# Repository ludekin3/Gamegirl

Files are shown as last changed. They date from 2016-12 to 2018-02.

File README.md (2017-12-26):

# Gamegirl

The most portable way to play LÖVE, PICO-8, Scratch or your favorite emulated games. Powered by RetroArch!

<p align="center">
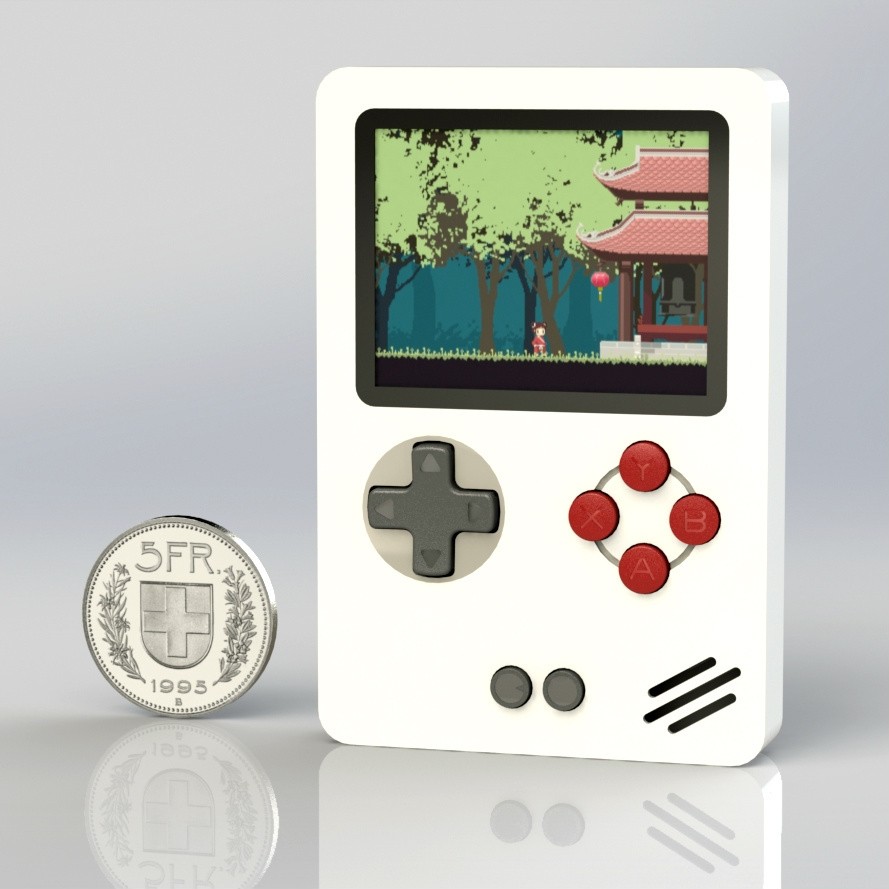
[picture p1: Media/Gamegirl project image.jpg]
Gamegirl
    
</p>

# Table of Contents

* [Description](#description)
* [Components](#components)
* [Build your own!](#build-your-own)
* [Setup](#setup)
* [Team](#team)
* [License](#license)

# Description
We develop a very small, affordable and portable gaming console with a 320x240 display at 120 FPS run by a Raspberry Pi Zero.
Gamegirl runs on the Lakka distribution powered by RetroArch because of its speed, fast power-on, instant power-off and its potential to run many retro and hipster-retro games (LÖVE, PICO-8, Scratch and emulators).

[**Join us on our Discord Chat Channel!**](https://discord.gg/TZ7MZEu)

<p align="center">
    <a href="http://www.youtube.com/watch?feature=player_embedded&v=z5BJ5ywMKEQ" target="_blank">Gamegirl Prototype v0.2</a>
</p>

**Project Goals:**
* Hardware accelerated display
* Custom software (Lakka / RetroArch)
* High quality case and buttons
* Small form factor

# Components
* 1 x Gamegirl custom PCB (audio, power, etc.)
* 1 × Raspberry Pi Zero
* 1 × 2.4" TFT display 320x240 (RGB 565 @ 120 FPS)
* 10 × soft rubber dome buttons
* 2 x metal dome buttons
* 1 × 15-16mm speaker
* 1 × 800+ mAh battery

# Build your own!

## Prototype v0.2 (_released_)
**v0.2** is the current development platform with multiple working prototypes in the field. It works but it's not perfect, yet!

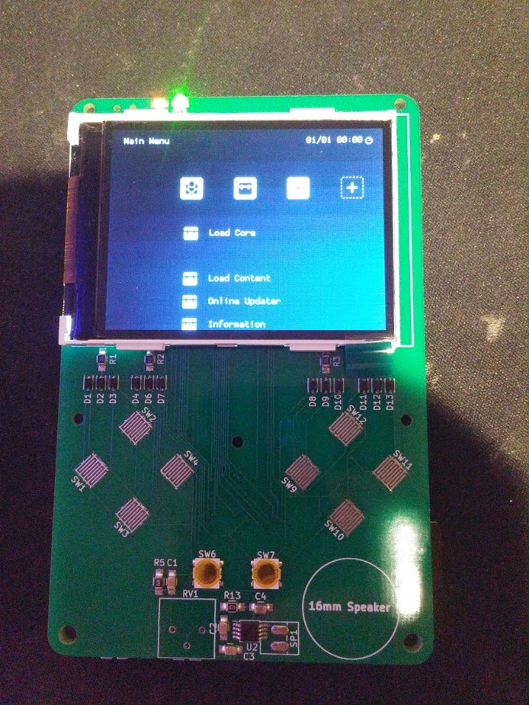
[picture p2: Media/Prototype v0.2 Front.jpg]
Prototype v0.2 Front

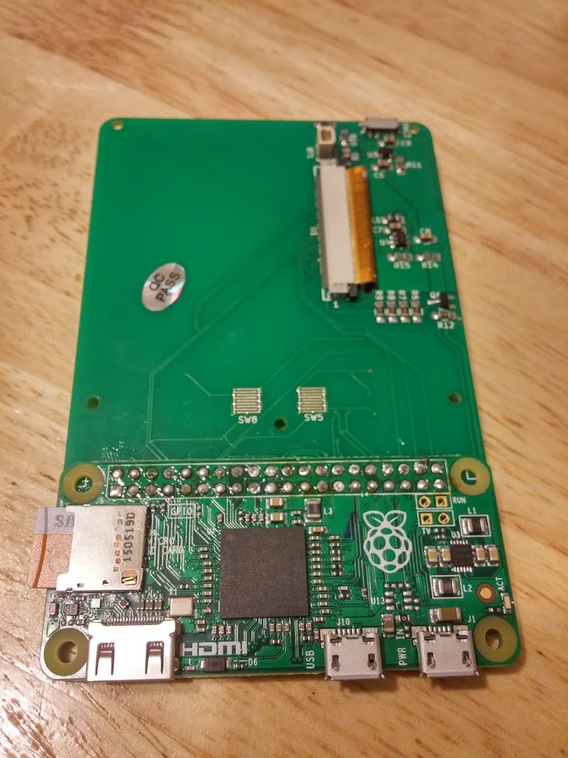
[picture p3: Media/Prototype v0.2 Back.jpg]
Prototype v0.2 Back


### Gamegirl v0.2 - Schematic
* [Gamegirl_v0.2_Schematic.pdf](./Electronics%20v0.2/Gamegirl_v0.2_Schematic.pdf)

### Gamegirl v0.2 - Bill Of Materials (BOM)
* [Octopart - Gamegirl v0.2 BOM](https://octopart.com/bom-tool/0X5BikOH)

#### Minimal assembly variant
In this assembly variant you will get a working prototype without battery/charging and audio functionality. You can use it only while the Raspberry Pi Zero is connected to a USB power supply!
* [Gamegirl v0.2 BOM - minimal assembly variant](./Electronics%20v0.2/Gamegirl_v0.2_BOM_minimal.pdf)

#### Full assembly variant
This assembly variant requires some circuit modifications to get audio output!
* [Gamegirl v0.2 BOM - full assembly variant](./Electronics%20v0.2/Gamegirl_v0.2_BOM.pdf)

### Gamegirl Case v0.2
A 3D printable case design is currently in work.

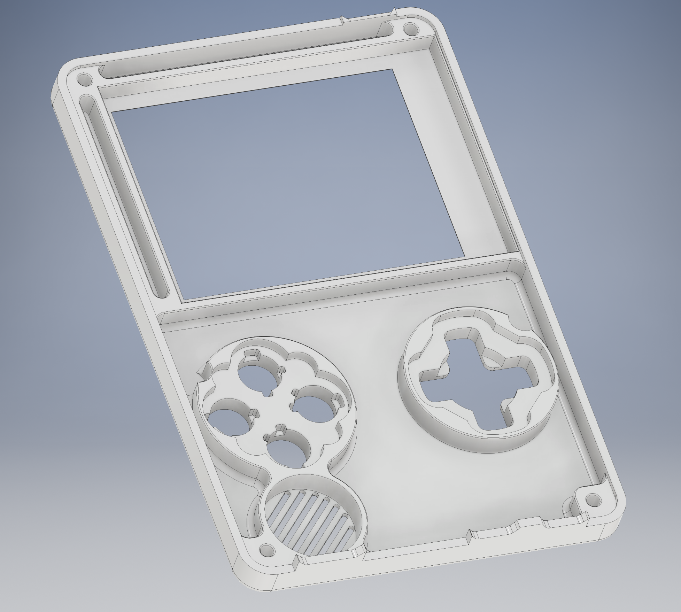
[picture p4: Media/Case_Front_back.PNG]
Case front design model


## Prototype v0.2.1 (Awaiting Prototype board)
**v0.2.1** incorporates multiple improvements and fixes over v0.2. If you do not have a v0.2, you should wait for this!

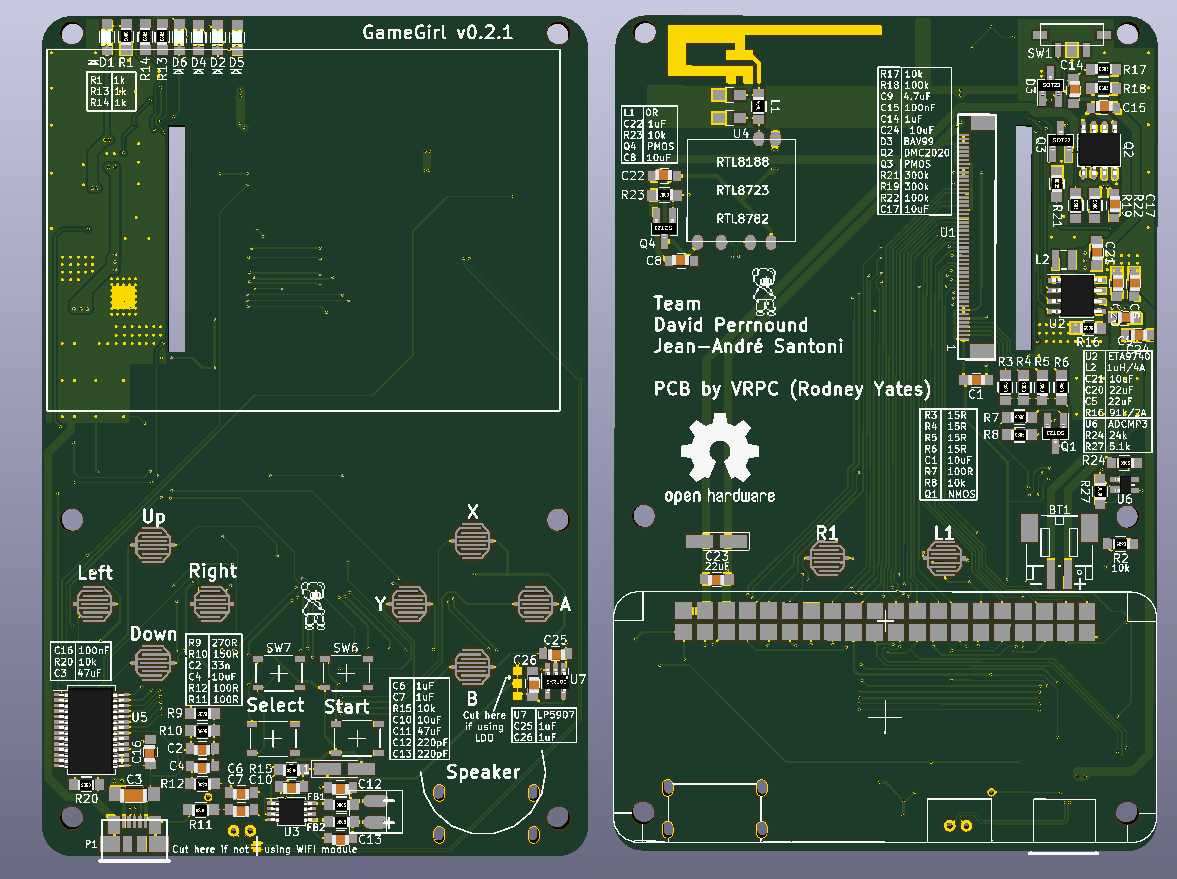
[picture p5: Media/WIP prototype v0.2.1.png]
Prototype v0.2.1 Front


**Improvements over v0.2:**
* Friendlier hand solderable layout (All component footprints have been expanded for soldering without a heatgun)
* Fixed mono audio circuit (better pre and post filtering)
* Fixed backlight function
* Button placement and labeling to reflect standard Nintendo layout
* MCP23S17 GPIO Expander replaced Charlieplexed buttons
* Labeled most 
* Ability to add common inexpensive WiFi adpater directly to the board (depreciated due to Zero W)
* Replaced battery charger and 5v booster ICs with a 3-in-1 IC, ETA9740
** Rpi Zero will run directly from battery (Rpi stability has been tested down to 3.0V)
** Increased charging current from 500mA to 2A or 3A
** 5V Boost will operate in USB-OTG mode for accessories
* Added dedicated charging micro USB port (Rpi ports will be covered)
* Added multiple power decoupling capacitors for better power filtering
* Added Safe Soft-Shutdown circuit
* Replaced latching switch with momentary switch
* (Optional) Low Battery shutdown
* (Optional) Low Noise LDO for audio amp (Must cut 3.3v trace when using)

### Gamegirl v0.2.1 - Bill Of Materials (BOM)
[BOM](./Electronics%20v0.2.1/Gamegirl_v0.2.1_BOM.csv)

### Gamegirl Case v0.2.1
(work in progress)

# Setup
## Install the latest Lakka image on an SD Card

**Gamegirl Raspberry Pi Zero images:**
* [Nightly Builds](http://sources.lakka.tv/nightly/Gamegirl.arm-8.0/)
* [Build r21684 (November 29, 2016)](http://static.kivutar.me/Lakka-Gamegirl.arm-devel-20161129161645-r21684-g895e996.img.gz)
* [Build r21570 (August 23, 2016)](http://static.kivutar.me/Lakka-Gamegirl.arm-devel-20160823060147-r21570-g1cacbe2.img.gz)

**Instructions:**
* [How to write a image to an SD card on Windows & Mac OS](http://trendblog.net/install-raspbian-sd-card-os-x-windows/)

## First boot
As of nightly build 20170110005640-r25097, the system will take longer to boot as it is expanding the SD card partition and running other first boot operations. Subsequent boots will be faster.

## Installing your games
How-to [on lakka.tv](http://www.lakka.tv/get/linux/rpi/install/first-boot/games/)

# Team
| David Perrenoud | Jean-André Santoni |  Rodney Yates
| --- | --- | --- |
| [David Perrenoud](https://github.com/davidperrenoud) | [Jean-André Santoni](http://www.kivutar.me/) - [Github](https://github.com/Kivutar) | [Rodney Yates](https://github.com/zybeon)

- [Jean-André] from France is the software guy of this project. He is the main Lakka developer and a top 5 RetroArch contributor.
- [David] from Switzerland is the hardware guy.
- [Rodney] from US is the PCB designer.

## Contributing
[Join us on our Discord Chat Channel!](https://discord.gg/TZ7MZEu)

### Project Task Tracker
[Trello page](https://trello.com/b/wslfYlVv/gamegirl)

#License

All hardware is covered under [OSHW](https://www.oshwa.org/definition/).

All software is covered under [GNU-GPL 3.0](https://opensource.org/licenses/GPL-3.0).

Permission is hereby granted, free of charge, to any person obtaining a copy of this software and associated documentation files (the "Software"), to deal in the Software without restriction, including without limitation the rights to use, copy, modify, merge, publish, distribute, sublicense, and/or sell copies of the Software, and to permit persons to whom the Software is furnished to do so, subject to the following conditions:  The above copyright notice and this permission notice shall be included in all copies or substantial portions of the Software. THE SOFTWARE IS PROVIDED "AS IS", WITHOUT WARRANTY OF ANY KIND, EXPRESS OR IMPLIED, INCLUDING BUT NOT LIMITED TO THE WARRANTIES OF MERCHANTABILITY, FITNESS FOR A PARTICULAR PURPOSE AND NONINFRINGEMENT. IN NO EVENT SHALL THE AUTHORS OR COPYRIGHT HOLDERS BE LIABLE FOR ANY CLAIM, DAMAGES OR OTHER LIABILITY, WHETHER IN AN ACTION OF CONTRACT, TORT OR OTHERWISE, ARISING FROM, OUT OF OR IN CONNECTION WITH THE SOFTWARE OR THE USE OR OTHER DEALINGS IN THE SOFTWARE."

GNU GPLv3 Logo

OSHW Logo

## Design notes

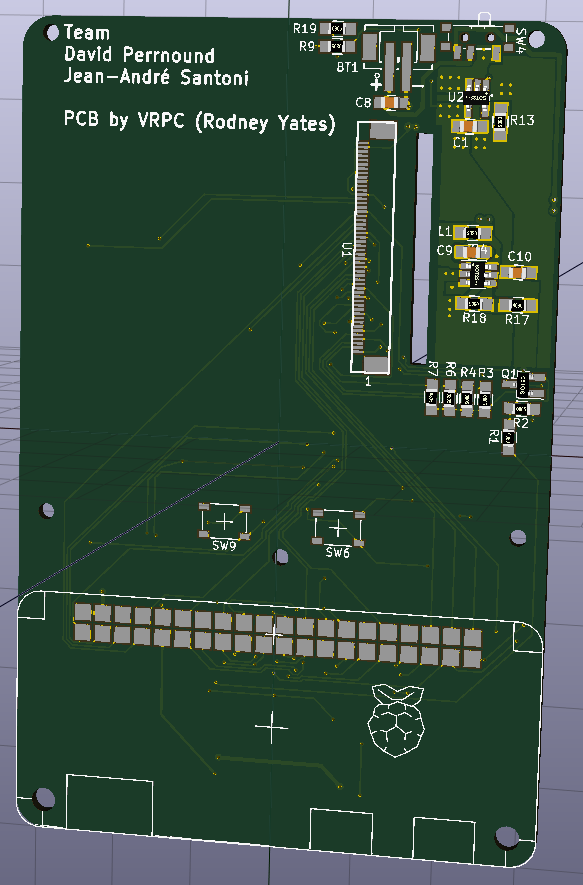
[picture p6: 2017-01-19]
Media/Design_Proto_v0.2.1_back.png

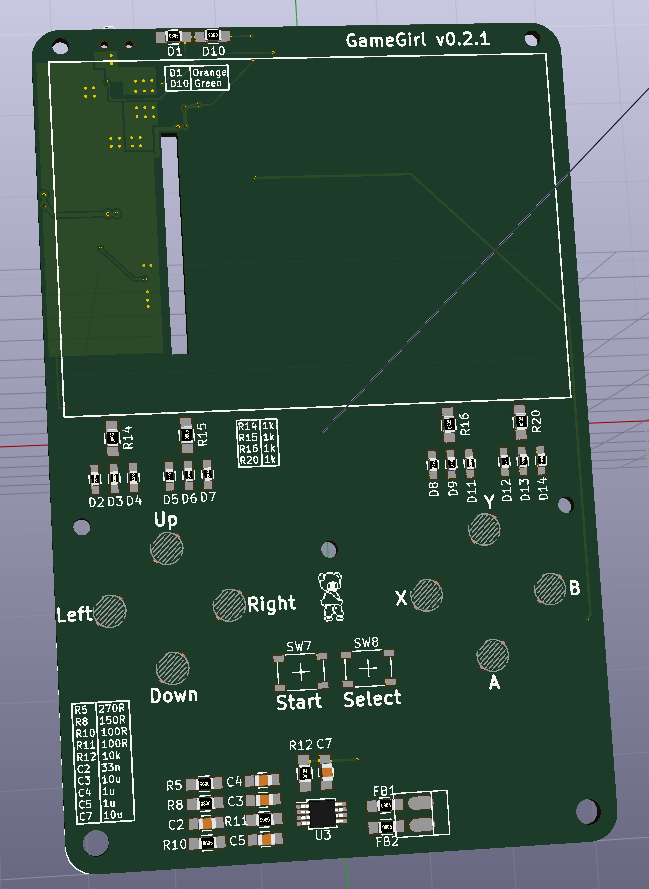
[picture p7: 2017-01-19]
Media/Design_Proto_v0.2.1_front.png

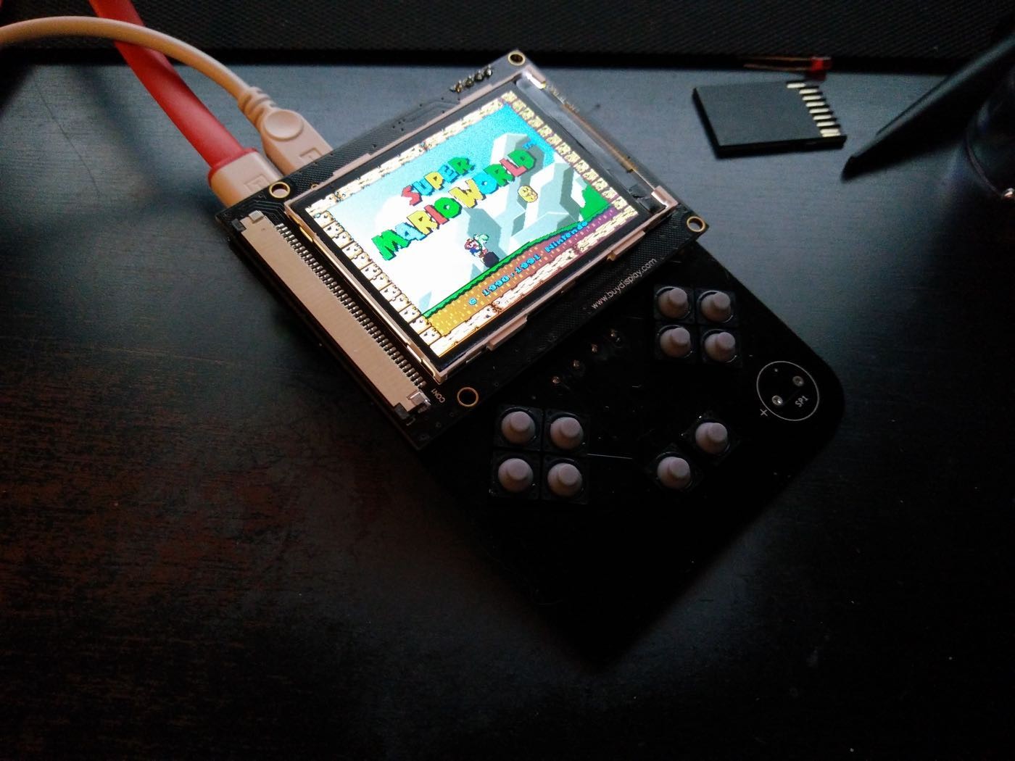
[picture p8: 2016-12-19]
Media/Gamegirl prototype v0.1.jpg

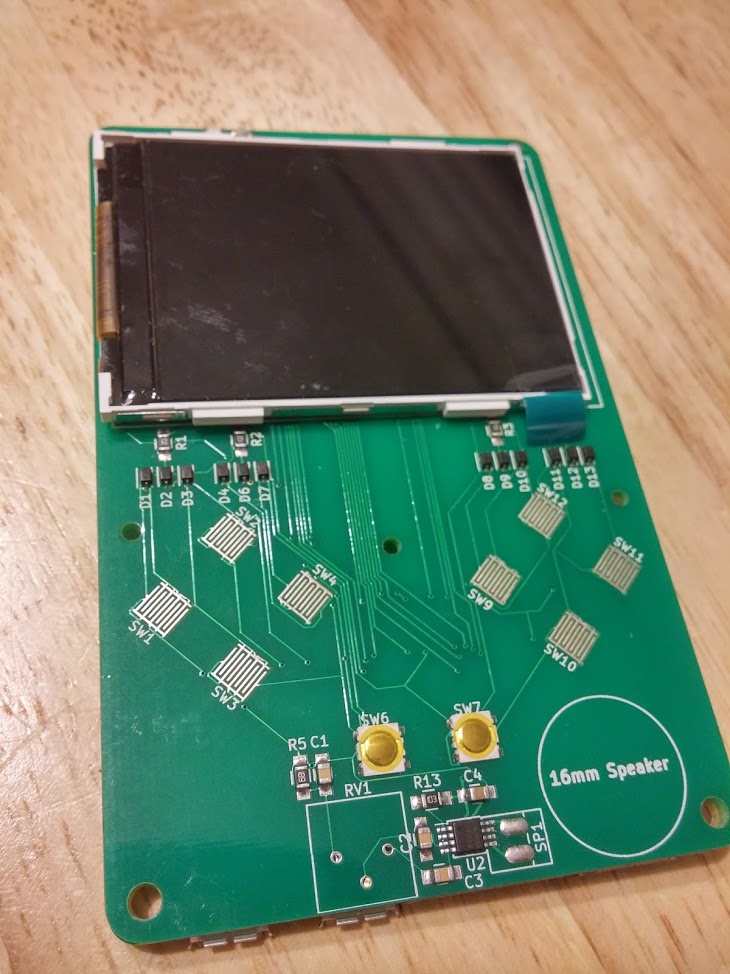
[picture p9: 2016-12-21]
Media/Prototype v0.2 Front 2.jpg

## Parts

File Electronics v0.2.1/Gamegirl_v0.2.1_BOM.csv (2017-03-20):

Reference | QTY | Value | Elecrow Part # | Arrow Part # | Mouser Part # | Description | Footprint | Datasheet
BT1 | 1 | Battery JST-PH |  | S2B-PH-SM4-TB | S2B-PH-SM4-TB | 2-pin JST-PH battery connector | JST_PH;2-pin;straight | http://www.jst-mfg.com/product/pdf/eng/ePH.pdf
C1;C10;C17;C21;C24 | 5 | 10uF | C15850 | GRM21BR71A106KA73L | LMK212B7106KG-TD | X7R | 0805(2012) | http://datasheet.octopart.com/LMK212B7106KG-TD-Taiyo-Yuden-datasheet-8857305.pdf
C2 | 1 | 33nF | C1739 | CL05B333KO5NNNC | 08055C333KAT4A | C0G or X7R, Audio Filter | 0805(2012) | http://datasheet.octopart.com/08055C333KAT4A-AVX-datasheet-12587061.pdf
C3 | 1 | 47uF |  | TAJA476K006SNJV | GRM31CR60J476ME19L | X5R/X7R or Tantalum | 1206(3216) | http://datasheet.octopart.com/GRM31CR60J476ME19L-Murata-datasheet-8328519.pdf
C4 | 1 | 10uF | C15850 | TAJR106M006RNJ | LMK212B7106KG-TD | Audio Filter; Tantalum or X7R | 0805(2012) | http://datasheet.octopart.com/LMK212B7106KG-TD-Taiyo-Yuden-datasheet-8857305.pdf
C5;C20;C23 | 3 | 22uF | C45783 | CL21A226MQQNNNE | GRM21BR60J226ME39L | Y5V-X7R | 0805(2012) | http://datasheet.octopart.com/GRM21BR60J226ME39L-Murata-datasheet-7563493.pdf
C6;C7 | 2 | 1uF | C28323 | CL21B105KAFNNNE | CC0805ZRY5V7BB105 | Audio Filter; Tantalum or X7R | 0805(2012) | http://datasheet.octopart.com/CC0805ZRY5V7BB105-Yageo-datasheet-68297955.pdf
C9 | 1 | 4.7uF | C1779 | CL21B475KQFNNNE | C2012X7R1A475M125AC | X7R | 0805(2012) | http://datasheet.octopart.com/C2012X7R1A475M125AC-TDK-datasheet-10978788.pdf
C11 | 1 | 47uF |  | TAJA476K006SNJV | TCJA476M006R0200 | Tantalum 47uF-100uF 6V+ | 1206(3216) | http://datasheet.octopart.com/TCJA476M006R0200-AVX-datasheet-10028634.pdf
C12;C13 | 2 | 220pF | C53172 | CL21C221JBANNNC | CC0805JRX7R9BB221 | C0G or X7R, Audio Filter | 0805(2012) | http://datasheet.octopart.com/CC0805JRX7R9BB221-Yageo-datasheet-12526321.pdf
C14 | 1 | 1uF | C28323 | CL21B105KAFNNNE | CC0805ZRY5V7BB105 | Y5V-X7R | 0805(2012) | http://datasheet.octopart.com/CC0805ZRY5V7BB105-Yageo-datasheet-68297955.pdf
C15;C16 | 2 | 0.1uF | C49678 | CL21B104KBCNNND | CL21B104KBCNNND | X7R | 0805(2012) | http://datasheet.octopart.com/CL21B104KBCNNND-Samsung-datasheet-59220082.pdf
D1;D2;D4;D5;D6 | 5 | LED_Green |  | LTST-C170GKT | LTST-C170GKT | Green status LED | 0805(2012) | http://datasheet.octopart.com/LTST-C170GKT-Lite-On-datasheet-159307.pdf
D3 | 1 | D_Schottky_x2 |  | BAV99 | BAV99,235 | 2x Diode | SOT-23 | http://datasheet.octopart.com/BAV99%2C235-Philips-datasheet-10109661.pdf
FB1;FB2 | 2 | MPZ2012S101A |  | MPZ2012S101A | MPZ2012S101AT000 | Ferrite bead; 100ohm@100MHz | 0805(2012) | http://datasheet.octopart.com/MPZ2012S101AT000-TDK-datasheet-12512619.pdf
L2 | 1 | 1uH |  | SRN2512-1R0M | SRN2512-1R0M | 1-2.2uH; Isat>=3A | 1008(2520) | http://datasheet.octopart.com/SRN2512-1R0M-Bourns-datasheet-57227380.pdf
P1 | 1 | Molex 47346-0001 | 6020800A | 47346-1001 | 47346-1001 | USB micro port, SMD | Molex USB SMD micro | http://www.molex.com/pdm_docs/sd/473460001_sd.pdf
P2 | 1 | PI-ZERO |  |  |  | Raspberry Pi Zero v1.3 | Rpi Zero
Q1 | 1 | NMOS_GSD | 4021523A | NTR4501NT1G | NTR4503NT1G | N MOSFET (1=G,2=S,3=D) | SOT-23 | http://datasheet.octopart.com/NTR4503NT1G-ON-Semiconductor-datasheet-156384.pdf
Q2 | 1 | DMC2020 |  | DMC2020USD-13 | DMC2020USD-13 | N(.05 Ohm)/P(.1 Ohm) MOSFET | SOIC-8 | http://datasheet.octopart.com/DMC2020USD-13-Diodes-Inc.-datasheet-13708805.pdf
Q3 | 2 | PMOS_GSD | 4022023A | NTR2101PT1G | NTR2101PT1G | P MOSFET (1=G,2=S,3=D) | SOT-23 | http://datasheet.octopart.com/NTR2101PT1G-ON-Semiconductor-datasheet-162393.pdf
R1 | 1 | 2k | C17604 | RMCF0805JT2K00 | RC0805FR-072KL | 1% | 0805(2012) | http://datasheet.octopart.com/RC0805FR-072KL-Yageo-datasheet-8330313.pdf
R2;R8;R15;R17;R20 | 5 | 10k | C17414 | RMCF0805FT10K0 | RC0805FR-0710KL | 1% | 0805(2012) | http://datasheet.octopart.com/RC0805FR-0710KL-Yageo-datasheet-8330313.pdf
R6;R5;R4;R3 | 4 | 15R | C17480 | RMCF0805FT15R0 | RC0805FR-0715RL | 1% | 0805(2012) | http://datasheet.octopart.com/RC0805FR-0715RL-Yageo-datasheet-8330313.pdf
R7;R11;R12 | 3 | 100 | C17408 | RMCF0805FT100R | RC0805FR-07100RL | 1% | 0805(2012) | http://datasheet.octopart.com/RC0805FR-07100RL-Yageo-datasheet-8330313.pdf
R10 | 1 | 150 | C17471 | RMCF0805FT150R | RC0805FR-07150RL | 1% | 0805(2012) | http://datasheet.octopart.com/RC0805FR-07150RL-Yageo-datasheet-8330313.pdf
R13;R14 | 2 | 1k | C17513 | RMCF0805FT1K00 | RC0805FR-071KL | 1% | 0805(2012) | http://datasheet.octopart.com/RC0805FR-071KL-Yageo-datasheet-8330313.pdf
R16 | 1 | 91k | C17866 | RMCF0805FT91K0 | RC0805FR-0791KL | 1% | 0805(2012) | http://datasheet.octopart.com/RC0805FR-0791KL-Yageo-datasheet-8330313.pdf
R18;R22 | 2 | 100k | C17407 | RMCF0805FG100K | RC0805FR-07100KL | 1% | 0805(2012) | http://datasheet.octopart.com/RC0805FR-07100KL-Yageo-datasheet-67302840.pdf
R19;R21 | 2 | 300k | C17616 | RMCF0805FT300K | RC0805FR-07300KL | 1% | 0805(2012) | http://datasheet.octopart.com/RC0805FR-07300KL-Yageo-datasheet-8330313.pdf
R9 | 1 | 270 |  | RMCF0805FT270R | RC0805FR-07270RL | 1% | 0805(2012) | http://datasheet.octopart.com/RC0805FR-07270RL-Yageo-datasheet-8330313.pdf
SW1 | 1 | JSX08001SAQNL |  | JSX08001S | JSX08001SAQNL | Momentary Power Switch | JSX Series switch | http://datasheet.octopart.com/JSX08001SAQNL-C%26K-Components-datasheet-27907546.pdf
U1 | 1 | ER-TFT024-3 |  | 54104-5031 | 54104-5033 | LCD FPC 50 pin connector | FPC/FFC-50 0.5mm | http://www.buydisplay.com/download/manual/ER-TFT024-3_Datasheet.pdf
U2 | 1 | ETA9740 |  |  |  | Charger/Booster | SOIC-8
U3 | 1 | PAM8302A |  | PAM8302AASCR | PAM8302AASCR | Audio Amp | MSOP-8 | http://datasheet.octopart.com/PAM8302AASCR-Diodes-Inc.-datasheet-17559798.pdf
U5 | 1 | MCP23S17 |  | MCP23S17-E/SS | MCP23S17-E/SS | SPI GPIO Expander | SSOP-28 | http://datasheet.octopart.com/MCP23S17-E/SS-Microchip-datasheet-166052.pdf
WiFi (OPTIONAL)
C8 | 1 | 10uF | C15850 | GRM21BR71A106KA73L | LMK212B7106KG-TD | X7R | 0805(2012) | http://datasheet.octopart.com/LMK212B7106KG-TD-Taiyo-Yuden-datasheet-8857305.pdf
C22 | 1 | 1uF | C28323 | CL21B105KAFNNNE | CC0805ZRY5V7BB105 | Y5V-X7R | 0805(2012) | http://datasheet.octopart.com/CC0805ZRY5V7BB105-Yageo-datasheet-68297955.pdf
R23 | 1 | 10k | C17414 | RMCF0805FT10K0 | RC0805FR-0710KL | 1% | 0805(2012) | http://datasheet.octopart.com/RC0805FR-0710KL-Yageo-datasheet-8330313.pdf
L1;R25;R26 | 3 | 0R | C17477 | RMCF0805ZT0R00 | RC0805FR-070RL | 0 ohm jumper | 0805(2012) | http://datasheet.octopart.com/RC0805FR-070RL-Yageo-datasheet-8330313.pdf
Q4 | 2 | PMOS_GSD | 4022023A | NTR2101PT1G | NTR2101PT1G | P MOSFET (1=G,2=S,3=D) | SOT-23 | http://datasheet.octopart.com/NTR2101PT1G-ON-Semiconductor-datasheet-162393.pdf
U4 | 1 | RTL8188EUS |  |  |  | USB WiFi Module | WiFi USB Module | https://www.aliexpress.com/item/1PCS-Low-power-WIFI-module-RTL8188EUS-chip-signal-receiving-module/32722318911.html
Low Noise LDO (Optional)
U7 | 1 | LP5907-3 |  | LP5907MFX-3.0/NOPB | LP5907MFX-3.0/NOPB | Ultra Low Noise LDO for Audio Amp | SOT23-5 | http://www.ti.com/lit/gpn/lp5907
C25;C26 | 2 | 1uF | C28323 | CL21B105KAFNNNE | CC0805ZRY5V7BB105 | Y5R/X7R | 0805(2012) | http://datasheet.octopart.com/CC0805ZRY5V7BB105-Yageo-datasheet-68297955.pdf
Low Battery (Optional)
U6 | 1 | ADCMP354 |  | ADCMP354YKSZ | ADCMP354YKSZ | Single Comparator, 0.6v reference | SC82 | http://datasheet.octopart.com/ADCMP354YKSZ-Analog-Devices-datasheet-10619861.pdf
R24 | 1 | 24k | C17575 |  |  | 1% | 0805(2012)
R27 | 1 | 5.1k | C27834 |  |  | 1% | 0805(2012)

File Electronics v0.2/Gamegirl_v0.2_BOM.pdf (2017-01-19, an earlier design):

Item | Description | Reference | Distributor | Part Number | Quantity | Unit price $ | Unit price € | Comment
PCB | oshpark | 1 | USD 50.55 | 1
PI-ZERO | Raspberry Pi Zero - Version 1.3 (https://www.adafruit.com/products/2885) | | adafruit | | 1 | USD 5.00
2'500mAh battery | Lithium Ion Polymer Battery - 3.7v 2500mAh (https://www.adafruit.com/products/328) | | adafruit | | 1 | USD 14.95
8bitdo Zero | | | amazon | | | USD 16.99
ER-TFT024-3 | Display | | buydisplay | ER-TFT024-3 (http://www.buydisplay.com/default/color-2-4-inch-tft-lcd-module-display-touch-panel-240x320-dot-serial-spi) | 1 | USD 6.99

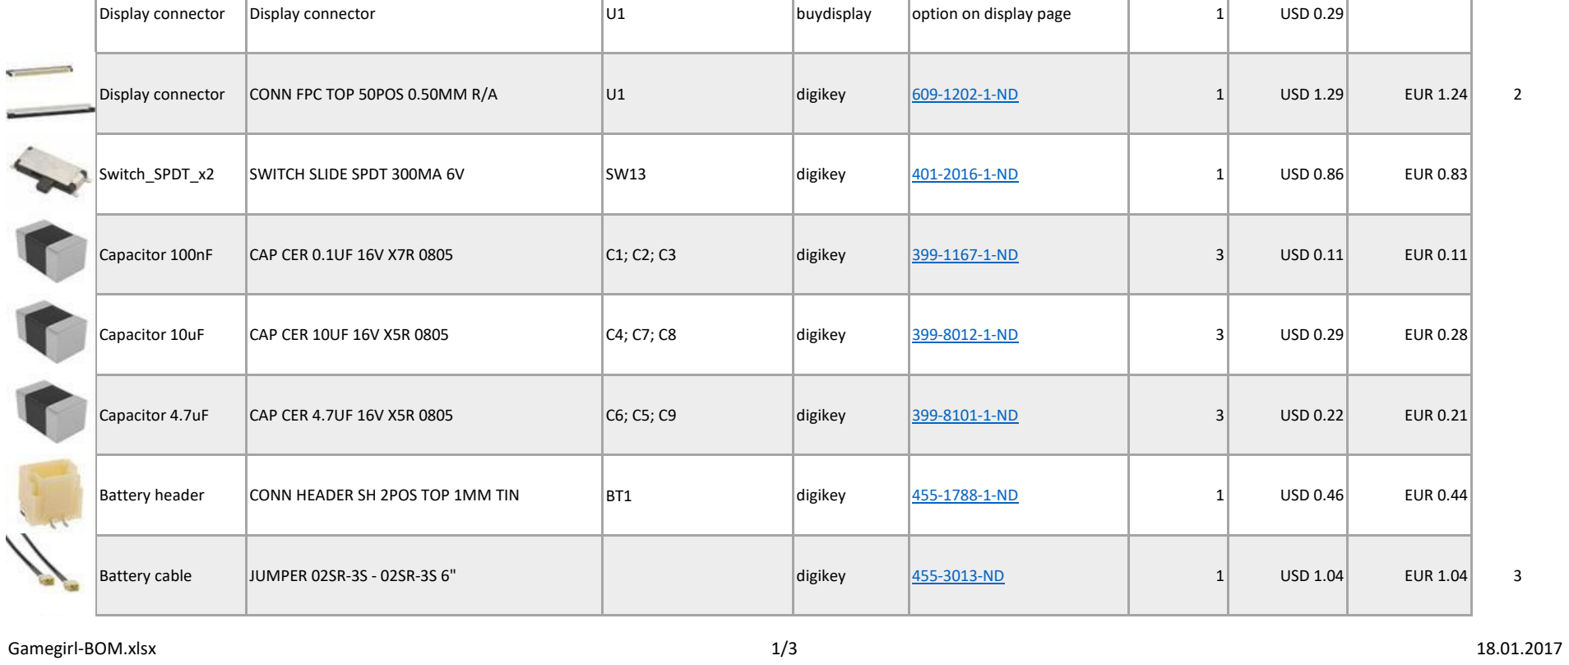
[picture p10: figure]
Display connector; buydisplay; option on display page; USD 0.29; Switch_SPDT_x2; SWITCH SLIDE SPDT 300MA 6V; digikey; 401-2016-1-ND (http://www.digikey.ch/scripts/DkSearch/dksus.dll?Detail&itemSeq=216191145&uq=636198271722988443); USD 0.86; EUR 0.83; Battery cable; JUMPER 02SR-3S - 02SR-3S 6"; USD 1.04; EUR 1.04; Gamegirl-BOM.xlsx

Display connector | CONN FPC TOP 50POS 0.50MM R/A | U1 | digikey | 609-1202-1-ND (http://www.digikey.ch/scripts/DkSearch/dksus.dll?Detail&itemSeq=216191156&uq=636198271722988443) | 1 | USD 1.29 | EUR 1.24 | 2
Capacitor 100nF | CAP CER 0.1UF 16V X7R 0805 | C1; C2; C3 | digikey | 399-1167-1-ND (http://www.digikey.ch/scripts/DkSearch/dksus.dll?Detail&itemSeq=216191143&uq=636198271722988443) | 3 | USD 0.11 | EUR 0.11
Capacitor 10uF | CAP CER 10UF 16V X5R 0805 | C4; C7; C8 | digikey | 399-8012-1-ND (http://www.digikey.ch/scripts/DkSearch/dksus.dll?Detail&itemSeq=216191142&uq=636198271722988443) | 3 | USD 0.29 | EUR 0.28
Capacitor 4.7uF | CAP CER 4.7UF 16V X5R 0805 | C6; C5; C9 | digikey | 399-8101-1-ND (http://www.digikey.ch/scripts/DkSearch/dksus.dll?Detail&itemSeq=216191141&uq=636198271722988443) | 3 | USD 0.22 | EUR 0.21
Battery header | CONN HEADER SH 2POS TOP 1MM TIN | BT1 | digikey | 455-1788-1-ND (http://www.digikey.ch/scripts/DkSearch/dksus.dll?Detail&itemSeq=216191150&uq=636198271722988443) | 1 | USD 0.46 | EUR 0.44

## Gamegirl-BOM v0.2

In order to simplify the sourcing of the parts, we tried to get all PCB components from one distributor. You might find them cheaper somewhere else!

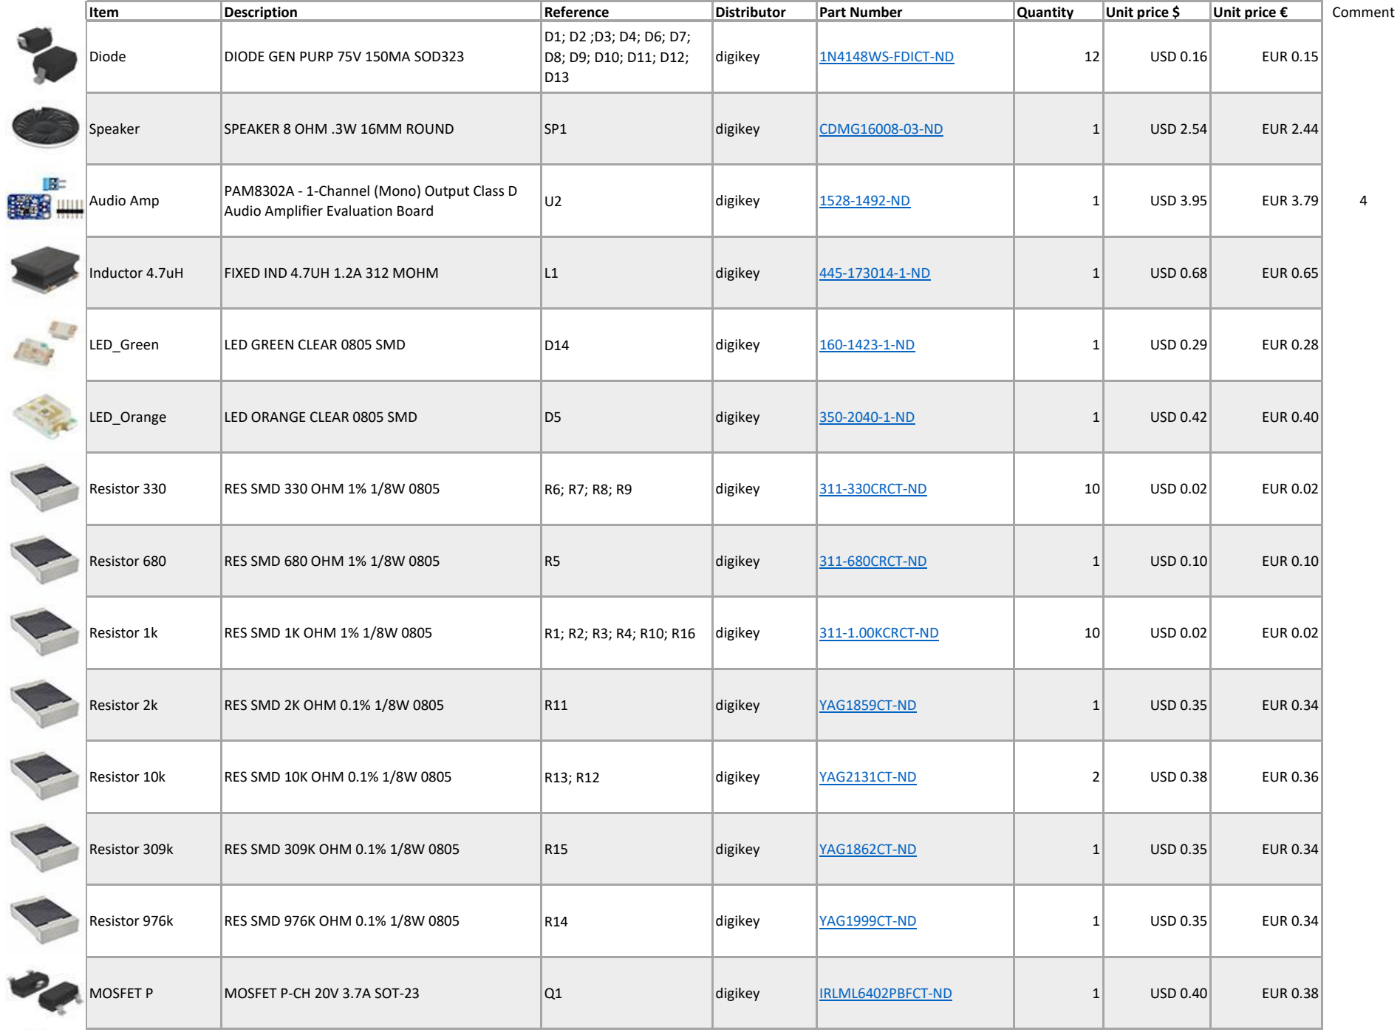
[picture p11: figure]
Item; Description; Reference; Distributor; Part Number; Quantity; Unit price $; Unit price €; Comment; Audio Amplifier Evaluation Board; digikey; USD 3.95; EUR 3.79; LED_Green; LED GREEN CLEAR 0805 SMD; 160-1423-1-ND (http://www.digikey.ch/scripts/DkSearch/dksus.dll?Detail&itemSeq=216191151&uq=636198271722988443); USD 0.29; EUR 0.28; LED_Orange; LED ORANGE CLEAR 0805 SMD; 350-2040-1-ND (http://www.digikey.ch/scripts/DkSearch/dksus.dll?Detail&itemSeq=216191154&uq=636198271722988443); USD 0.42; EUR 0.40; MOSFET P; MOSFET P-CH 20V 3.7A SOT-23; IRLML6402PBFCT-ND (http://www.digikey.ch/scripts/DkSearch/dksus.dll?Detail&itemSeq=216191146&uq=636198271722988443); USD 0.40; EUR 0.38

Diode | DIODE GEN PURP 75V 150MA SOD323 | D1; D2 ;D3; D4; D6; D7; D8; D9; D10; D11; D12; D13 | digikey | 1N4148WS-FDICT-ND (http://www.digikey.ch/scripts/DkSearch/dksus.dll?Detail&itemSeq=216191149&uq=636198271722988443) | 12 | USD 0.16 | EUR 0.15
Speaker | SPEAKER 8 OHM .3W 16MM ROUND | SP1 | digikey | CDMG16008-03-ND (https://www.digikey.ca/product-detail/en/cui-inc/CDMG16008-03/CDMG16008-03-ND/671245) | 1 | USD 2.54 | EUR 2.44
Audio Amp | PAM8302A - 1-Channel (Mono) Output Class D
Inductor 4.7uH | FIXED IND 4.7UH 1.2A 312 MOHM | L1 | digikey | 445-173014-1-ND (http://www.digikey.ch/scripts/DkSearch/dksus.dll?Detail&itemSeq=216191166&uq=636198271722988443) | 1 | USD 0.68 | EUR 0.65
Resistor 330 | RES SMD 330 OHM 1% 1/8W 0805 | R6; R7; R8; R9 | digikey | 311-330CRCT-ND (http://www.digikey.ch/scripts/DkSearch/dksus.dll?Detail&itemSeq=216191144&uq=636198271722988443) | 10 | USD 0.02 | EUR 0.02
Resistor 680 | RES SMD 680 OHM 1% 1/8W 0805 | R5 | digikey | 311-680CRCT-ND (http://www.digikey.ch/scripts/DkSearch/dksus.dll?Detail&itemSeq=216191153&uq=636198271722988443) | 1 | USD 0.10 | EUR 0.10
Resistor 1k | RES SMD 1K OHM 1% 1/8W 0805 | R1; R2; R3; R4; R10; R16 | digikey | 311-1.00KCRCT-ND (http://www.digikey.ch/scripts/DkSearch/dksus.dll?Detail&itemSeq=216191147&uq=636198271722988443) | 10 | USD 0.02 | EUR 0.02
Resistor 2k | RES SMD 2K OHM 0.1% 1/8W 0805 | R11 | digikey | YAG1859CT-ND (http://www.digikey.ch/scripts/DkSearch/dksus.dll?Detail&itemSeq=216191158&uq=636198271722988443) | 1 | USD 0.35 | EUR 0.34
Resistor 10k | RES SMD 10K OHM 0.1% 1/8W 0805 | R13; R12 | digikey | YAG2131CT-ND (http://www.digikey.ch/scripts/DkSearch/dksus.dll?Detail&itemSeq=216191155&uq=636198271722988443) | 2 | USD 0.38 | EUR 0.36
Resistor 309k | RES SMD 309K OHM 0.1% 1/8W 0805 | R15 | digikey | YAG1862CT-ND (http://www.digikey.ch/scripts/DkSearch/dksus.dll?Detail&itemSeq=216336658&uq=636199518906517429) | 1 | USD 0.35 | EUR 0.34
Resistor 976k | RES SMD 976K OHM 0.1% 1/8W 0805 | R14 | digikey | YAG1999CT-ND (http://www.digikey.ch/scripts/DkSearch/dksus.dll?Detail&itemSeq=216191157&uq=636198271722988443) | 1 | USD 0.35 | EUR 0.34
Gamegirl-BOM.xlsx | 2/3 | 18.01.2017

Item | Description | Reference | Distributor | Part Number | Quantity | Unit price $ | Unit price € | Comment
MCP73831-2ACI | IC CONTROLLR LI-ION 4.2V SOT23-5 | U3 | digikey | MCP73831T-2ACI/OTCT-ND (http://www.digikey.ch/scripts/DkSearch/dksus.dll?Detail&itemSeq=216191152&uq=636198271722988443) | 1 | USD 0.58 | EUR 0.56
MCP1640B | IC REG BST ADJ 0.35A SYNC SOT23 | U4 | digikey | MCP1640BT-I/CHYCT-ND (http://www.digikey.ch/scripts/DkSearch/dksus.dll?Detail&itemSeq=216191148&uq=636198271722988443) | 1 | USD 0.59 | EUR 0.57
Dome Switch | SWITCH TACTILE SPST-NO 0.05A 15V | SW6; SW7 | digikey | EG4622CT-ND (http://www.digikey.ch/scripts/DkSearch/dksus.dll?Detail&itemSeq=216191160&uq=636198271722832428) | 2 | USD 0.19 | EUR 0.18

Comment
1
2
3
4

You can only order three (or a multiple of three) Gamegirl PCBs from OSHPark. The unit price is for three PCBs!
This connector works as well. You can use it if you forget to order the connector together with the screen, which is cheaper.

The PAM8302A IC is not available at digikey. The evaluation board is an alternative.

The 2'500mAh battery comes with a bigger connector so we have to replace it to fit the header.

Gamegirl-BOM.xlsx | 3/3 | 18.01.2017

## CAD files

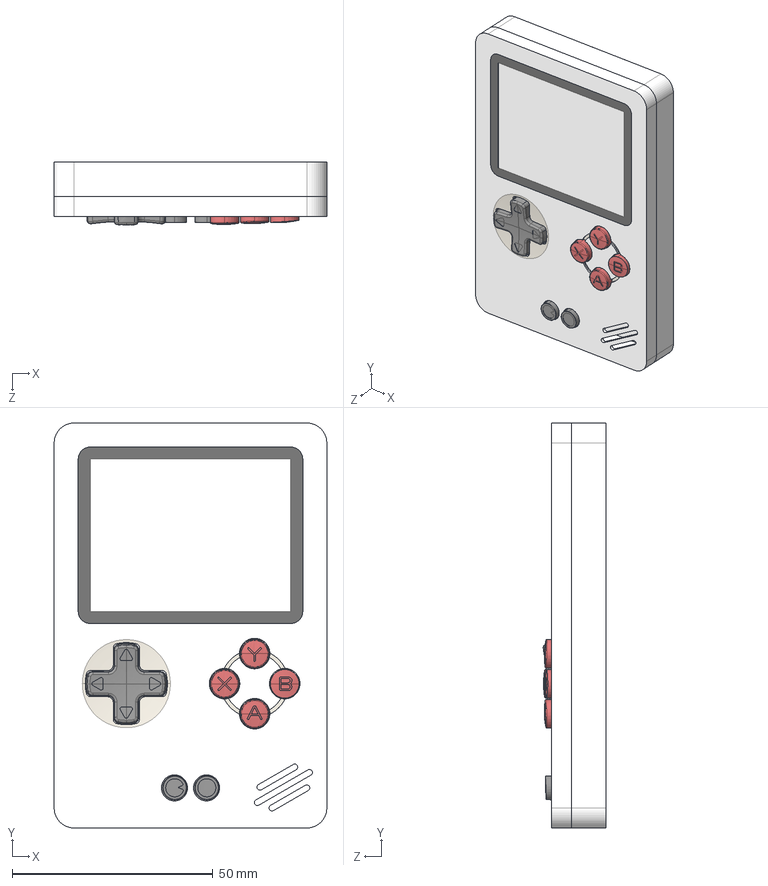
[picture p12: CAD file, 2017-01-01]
Mechanical/Gamegirl-2016-07-11.STEP
68.0 x 101.0 x 15.6 mm
GameGirl Back
GameGirl Front
Screen
Lakka Screen Protection
D-pad
Action Button
Start+Select

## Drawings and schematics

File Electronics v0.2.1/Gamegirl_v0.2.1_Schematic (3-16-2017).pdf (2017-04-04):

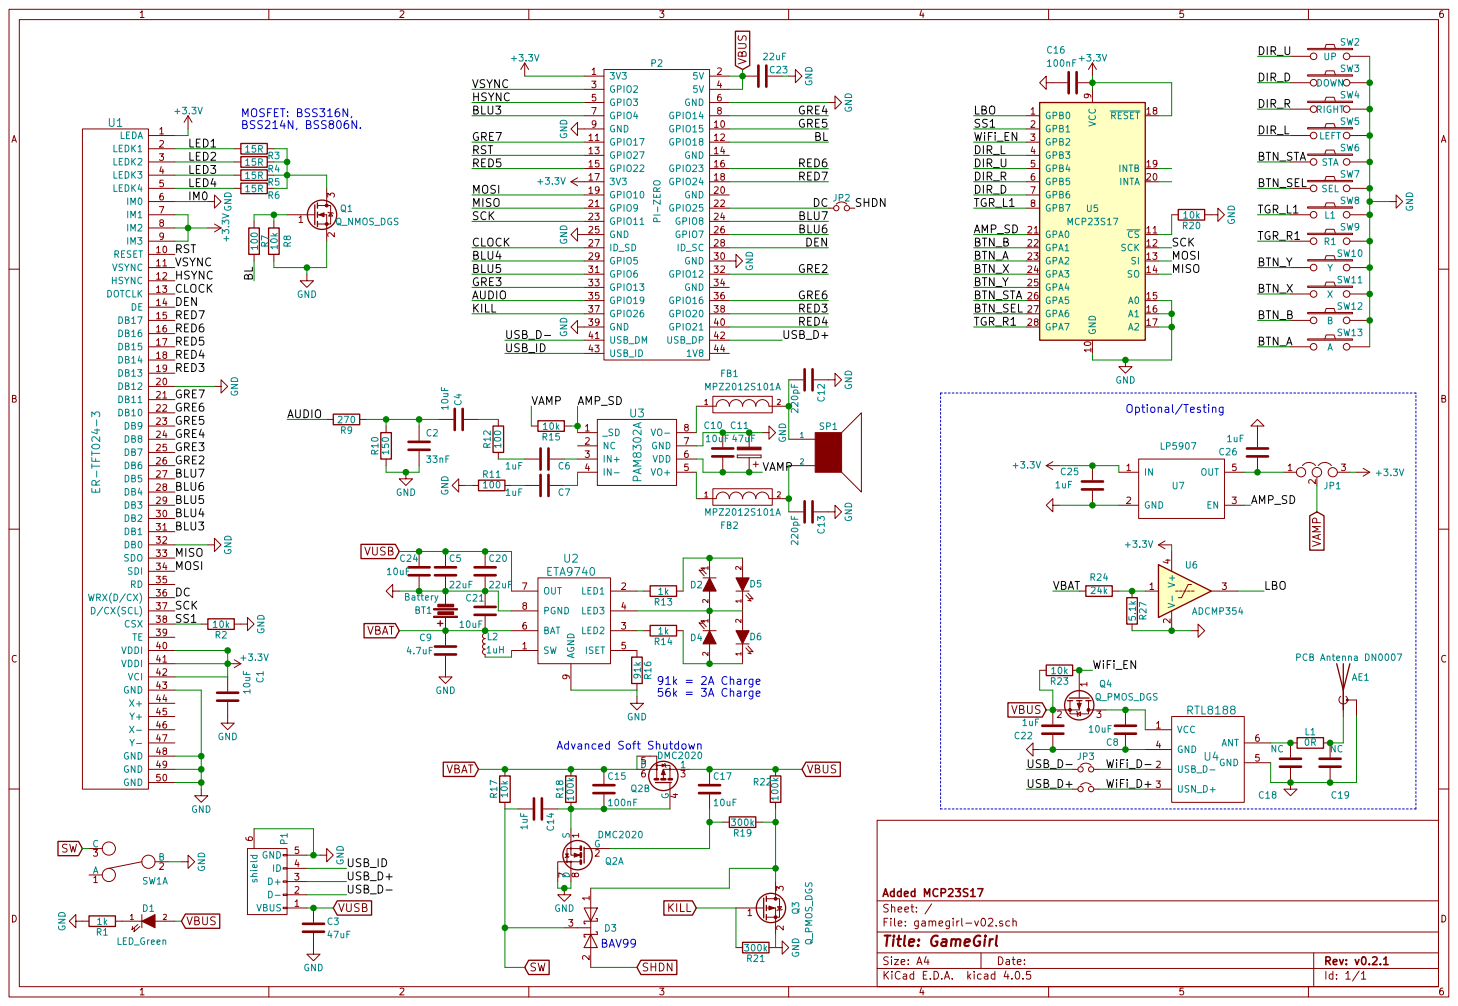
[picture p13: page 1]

File: gamegirl-v02.sch Sheet: / Added MCP23S17 GND

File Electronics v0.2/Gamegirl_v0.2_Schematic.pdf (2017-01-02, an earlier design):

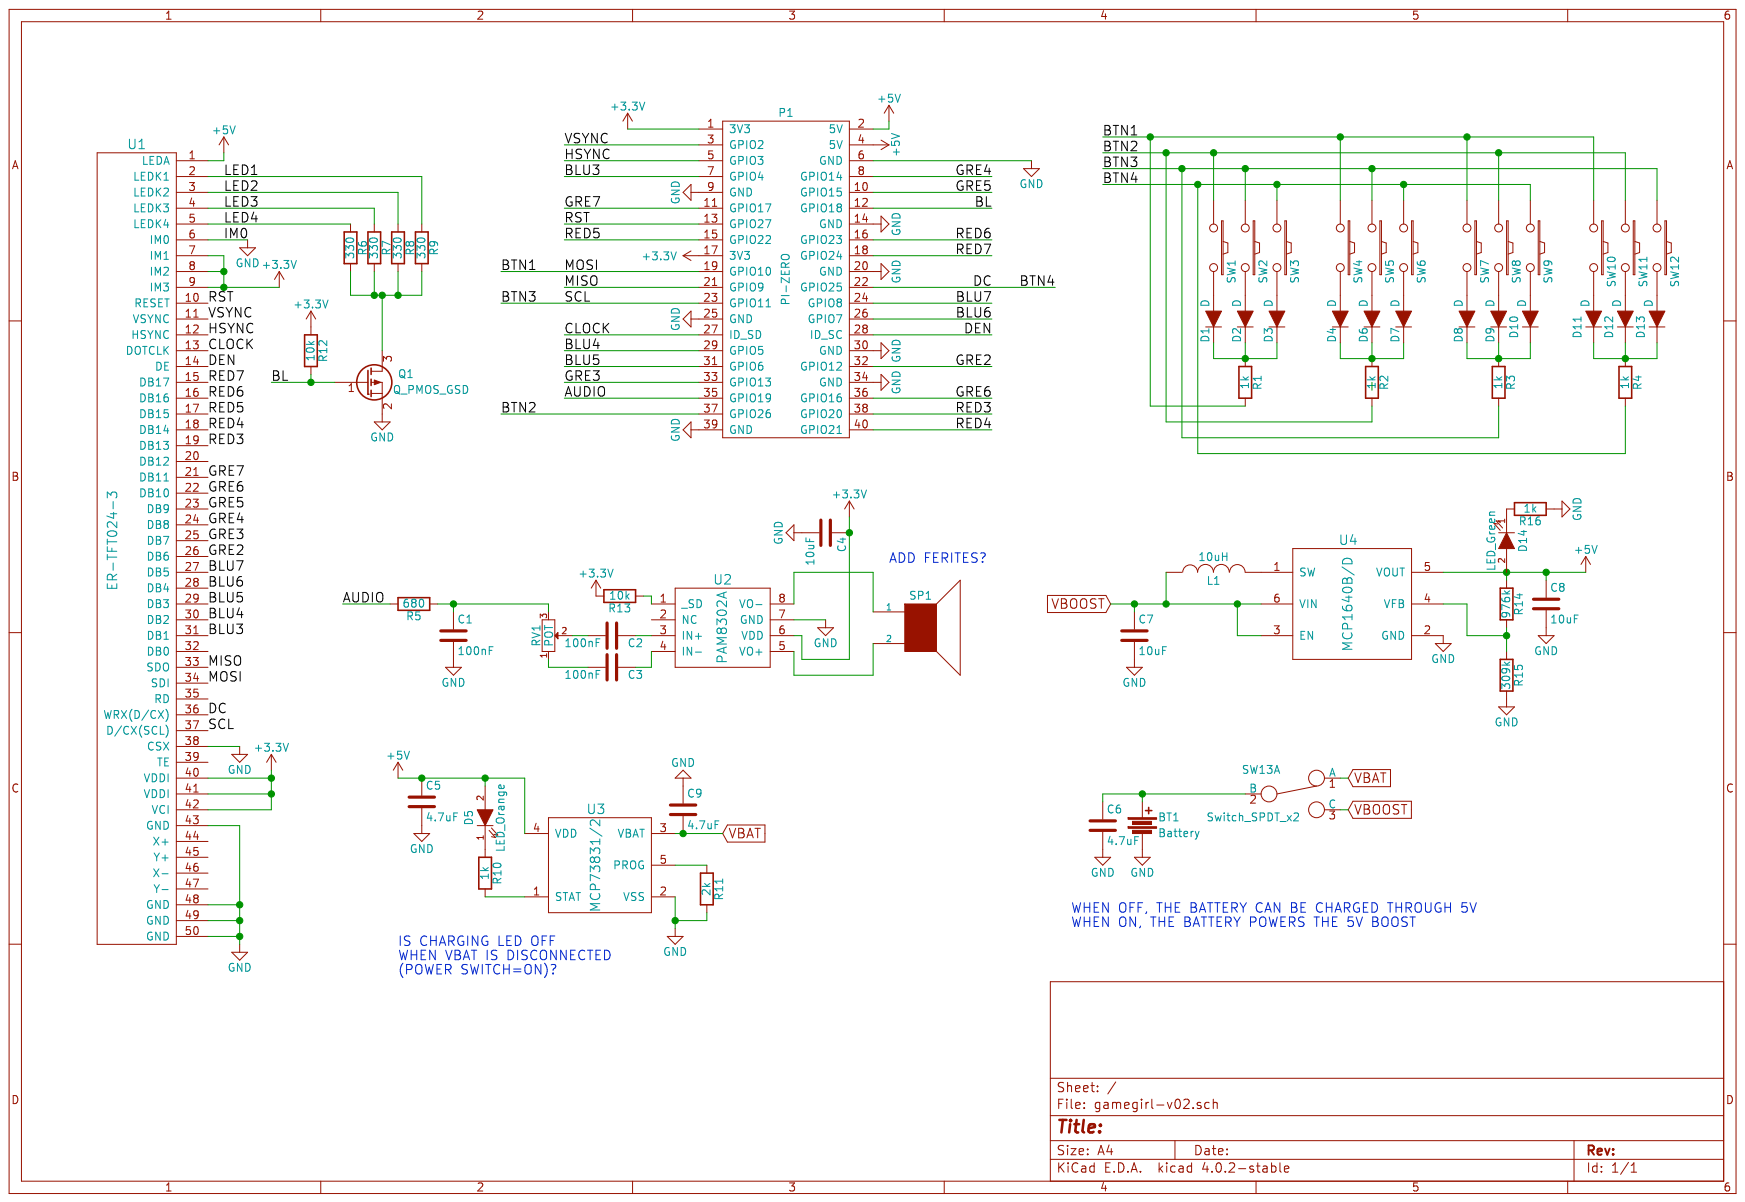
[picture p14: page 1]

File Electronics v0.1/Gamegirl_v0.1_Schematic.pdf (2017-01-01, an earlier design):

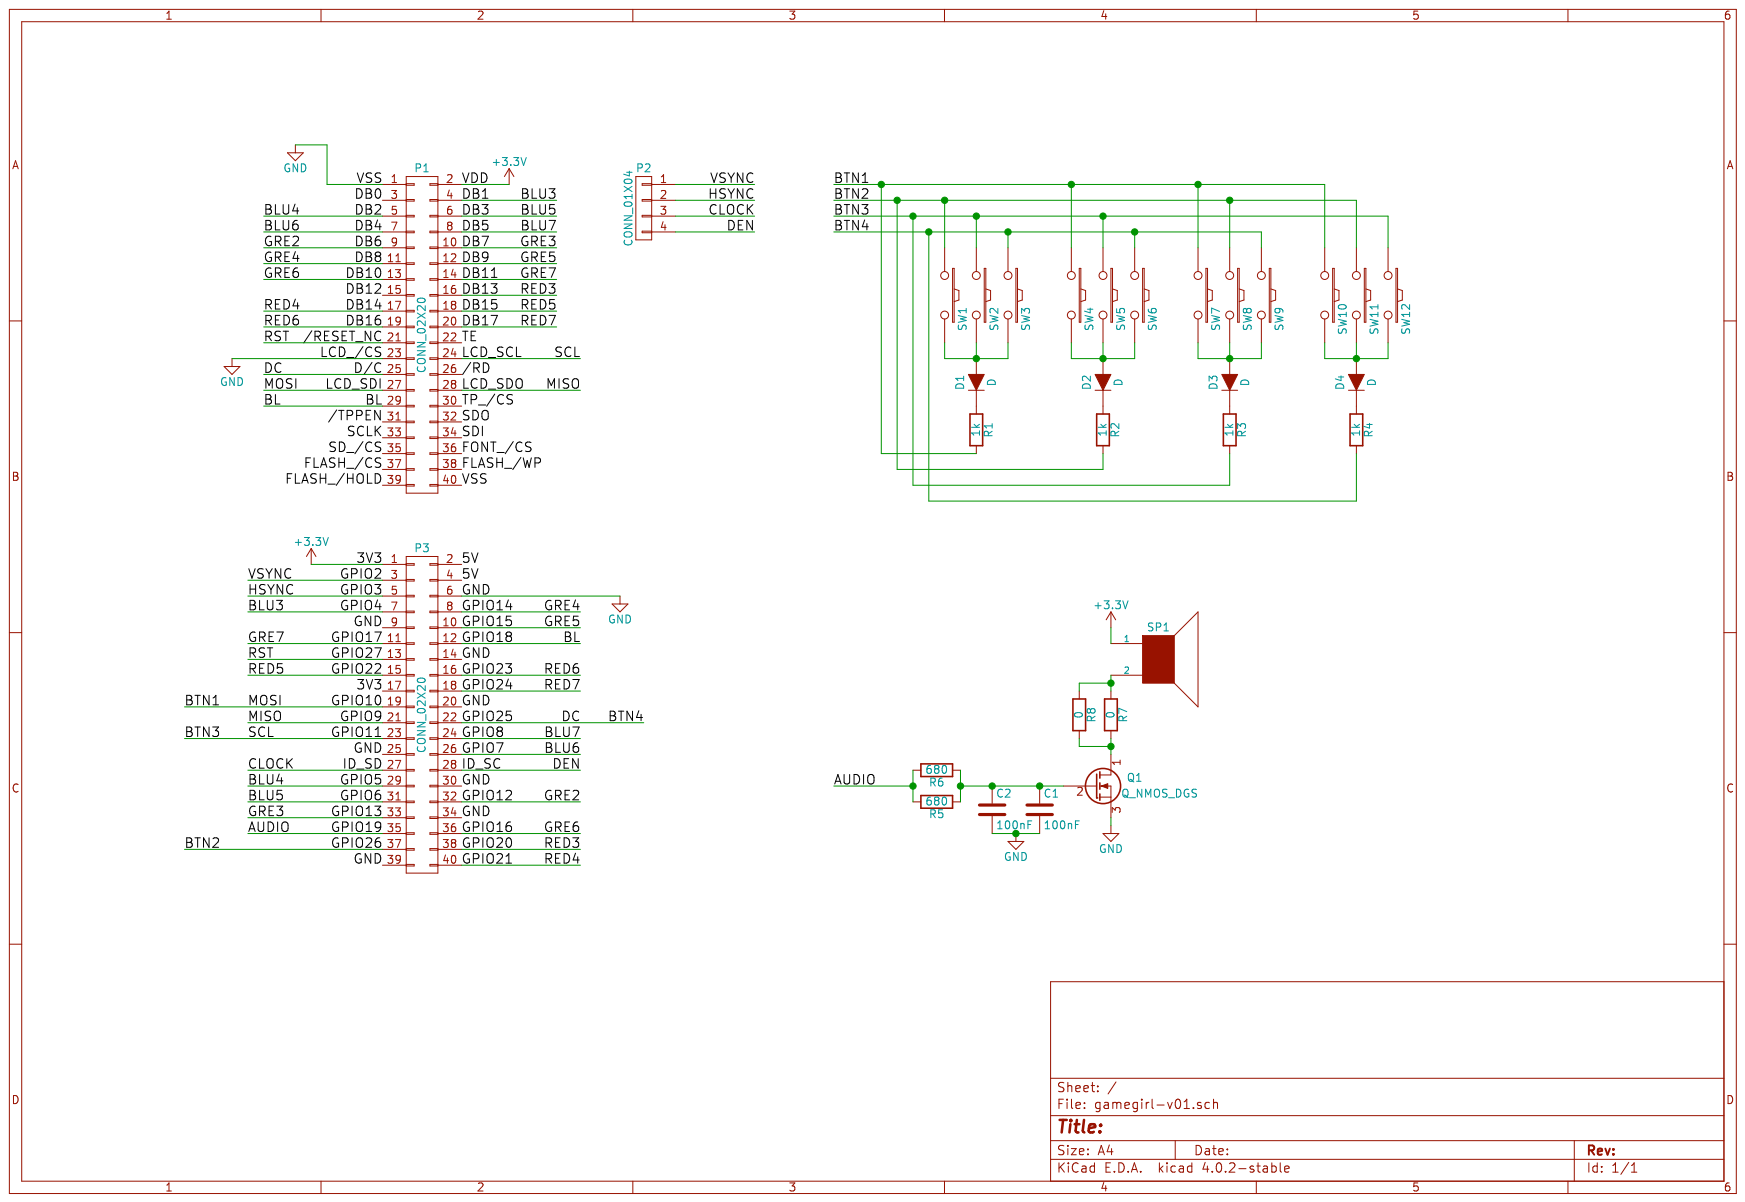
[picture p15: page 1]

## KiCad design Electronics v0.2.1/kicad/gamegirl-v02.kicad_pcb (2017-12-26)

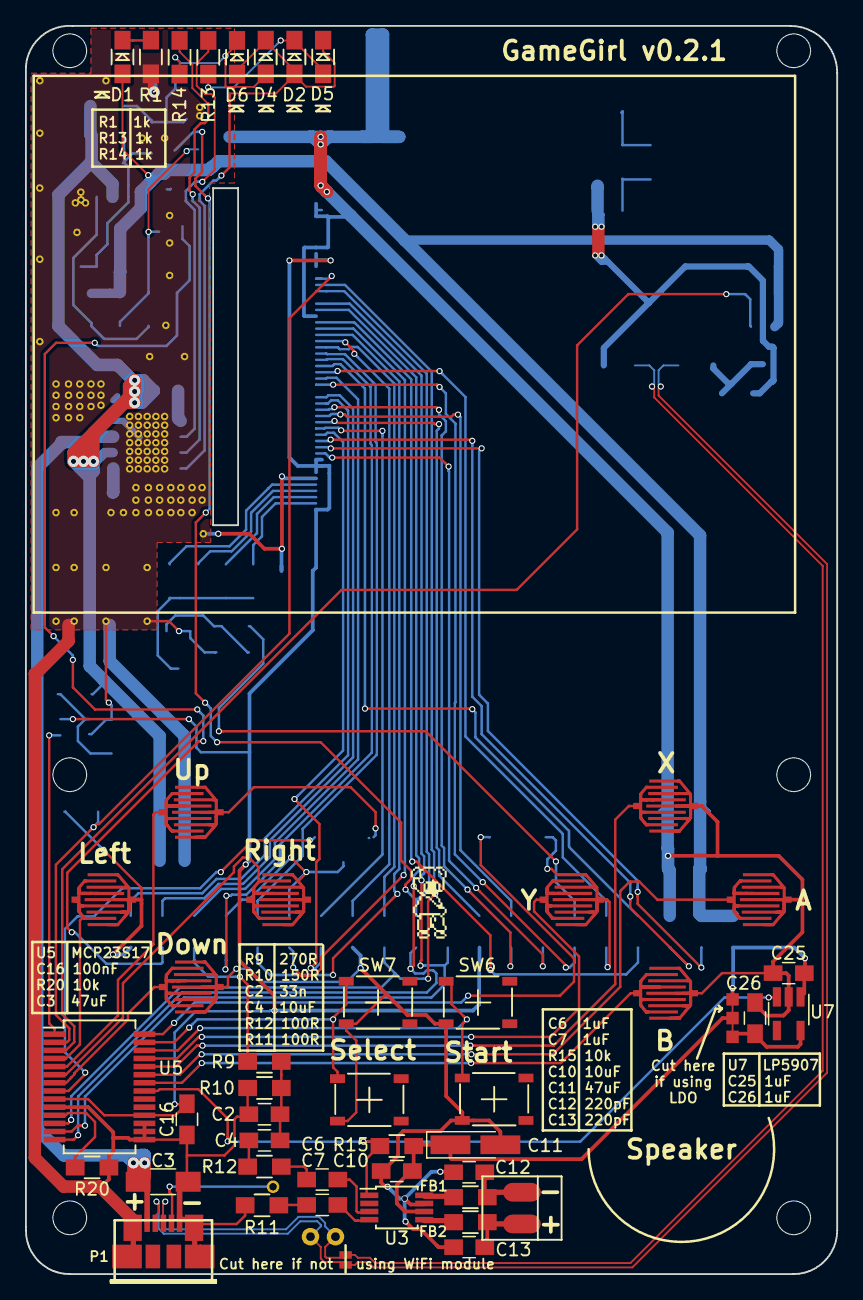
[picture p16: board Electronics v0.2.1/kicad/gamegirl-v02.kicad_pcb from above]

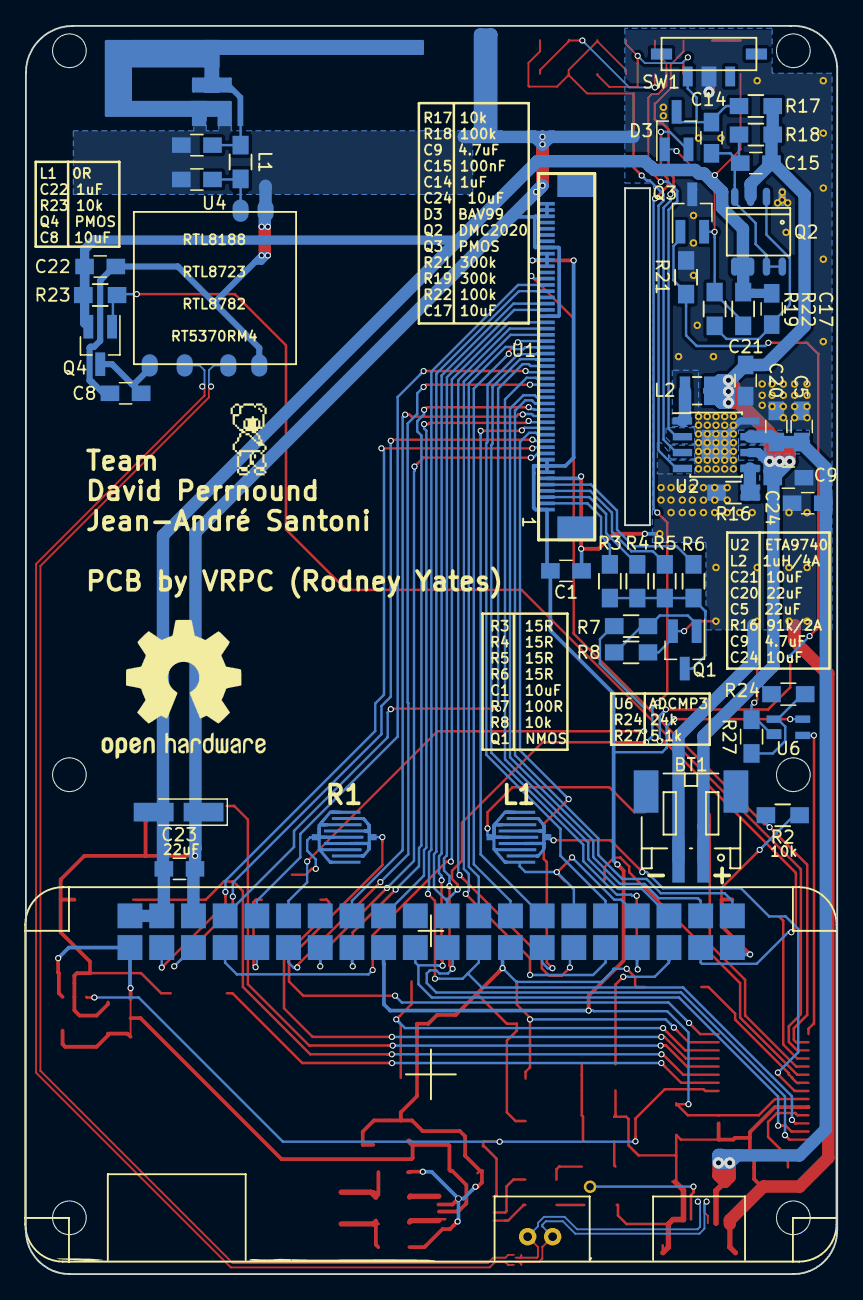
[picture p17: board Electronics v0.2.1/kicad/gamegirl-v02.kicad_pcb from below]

Board: 2 copper layers, 65.0 x 100.0 mm, 95 parts (48 on the bottom side), 90 nets.

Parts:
AE1: PCB Antenna DN0007; ANTENNA_TI_AN0007_2.4GHz
BT1: Battery; JST_PH_S2B-PH-SM4-TB_02x2.00mm_Extended
C1, C4, C8, C10, C17, C21, C24: 10uF; C_0805_HandSoldering
C2: 33nF; C_0805_HandSoldering
C3: 47uF; C_1206_HandSoldering
C5, C20, C23: 22uF; C_0805_HandSoldering
C6, C7, C14, C22, C25, C26: 1uF; C_0805_HandSoldering
C9: 4.7uF; C_0805_HandSoldering
C11: 47uF; CP_Tantalum_Case-A_EIA-3216-18_Hand
C12, C13: 220pF; C_0805_HandSoldering
C15, C16: 100nF; C_0805_HandSoldering
C18, C19: NC; C_0805_HandSoldering
D1, D2, D4, D5, D6: LED_Green; D_0805_HandSoldering
D3: D_Schottky_x2_KCom_AAK; SOT-23_Handsoldering
FB1, FB2: MPZ2012S101A; R_0805_HandSoldering
JP1: Jumper_NC_Dual; NetTie-II_SMD-Connected
JP2: Jumper_NC_Small; NetTie-I_Connected_SMD
JP3: Jumper_USB_90ohm; NetTie-USB_90ohm
L1: 0R; R_0805_HandSoldering
L2: 1uH; Inductor_Wurth_MAPI-2512
P1: Molex 47346-0001; conn_usb_B_micro_smd
P2: PI-ZERO; raspberry-zero
Q1: Q_NMOS_DGS; SOT-23_Handsoldering
Q2: DMC2020; SO-8
Q3, Q4: Q_PMOS_DGS; SOT-23_Handsoldering
R1, R13, R14: 1k; R_0805_HandSoldering
R2, R8, R15, R17, R20, R23: 10k; R_0805_HandSoldering
R3, R4, R5, R6: 15R; R_0805_HandSoldering
R7, R11, R12: 100; R_0805_HandSoldering
R9: 270; R_0805_HandSoldering
R10: 150; R_0805_HandSoldering
R16: 91k; R_0805_HandSoldering
R18, R22: 100k; R_0805_HandSoldering
R19, R21: 300k; R_0805_HandSoldering
R24: 24k; R_0805_HandSoldering
R27: 5.1k; R_0805_HandSoldering
SP1: SPEAKER; Speaker-Pinout
SW1: JSX08001SAQNL; JSX_Series_minature_switch
SW2: UP; round_rubber_pad_4.7mm
SW3: DOWN; round_rubber_pad_4.7mm
SW4: RIGHT; round_rubber_pad_4.7mm
SW5: LEFT; round_rubber_pad_4.7mm
SW6, SW6#2: STA; SW_DOME_4x4.6_SMD
SW7, SW7#2: SEL; SW_DOME_4x4.6_SMD
SW8: L1; round_rubber_pad_4.7mm
SW9: R1; round_rubber_pad_4.7mm
SW10: Y; round_rubber_pad_4.7mm
SW11: X; round_rubber_pad_4.7mm
SW12: B; round_rubber_pad_4.7mm
SW13: A; round_rubber_pad_4.7mm
U1: ER-TFT024-3; ER-CON50HT-1
U2: ETA9740; SOIC-8-1EP_3.9x4.9mm_Pitch1.27mm
U3: PAM8302A; MSOP-8_3x3mm_Pitch0.65mm
U4: RTL8188; RTL8188_WiFi_USB_module
U5: MCP23S17; SSOP-28_5.3x10.2mm_Pitch0.65mm
U6: ADCMP354; SC-82_handsolderable
U7: LP5907; SOT-23-5_HandSoldering

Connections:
+3V3: C1.2, C16.1, C25.2, JP1.3, P2.1, P2.17, U1.1, U1.7, U1.8, U1.9, U1.40, U1.41, U1.42, U5.9, U5.18, U6.4, U7.1
/AMP_SD: R15.1, U3.1, U5.21, U7.3
/AUDIO: P2.35, R9.2
/BL: P2.12, R7.2
/BLU3: P2.7, U1.31
/BLU4: P2.29, U1.30
/BLU5: P2.31, U1.29
/BLU6: P2.26, U1.28
/BLU7: P2.24, U1.27
/BTN_A: SW13.1, U5.23
/BTN_B: SW12.1, U5.22
/BTN_SEL: SW7.1, SW7#2.1, U5.27
/BTN_STA: SW6.1, SW6#2.1, U5.26
/BTN_X: SW11.1, U5.24
/BTN_Y: SW10.1, U5.25
/CLOCK: P2.27, U1.13
/DC: JP2.1, P2.22, U1.36
/DEN: P2.28, U1.14
/DIR_D: SW3.1, U5.7
/DIR_L: SW5.1, U5.4
/DIR_R: SW4.1, U5.6
/DIR_U: SW2.1, U5.5
/GRE2: P2.32, U1.26
/GRE3: P2.33, U1.25
/GRE4: P2.8, U1.24
/GRE5: P2.10, U1.23
/GRE6: P2.36, U1.22
/GRE7: P2.11, U1.21
/HSYNC: P2.5, U1.12
/KILL: P2.37, Q3.1, R21.2
/LBO: U5.1, U6.3
/LED1: R3.2, U1.2
/LED2: R4.2, U1.3
/LED3: R5.2, U1.4
/LED4: R6.2, U1.5
/MISO: P2.21, U1.33, U5.14
/MOSI: P2.19, U1.34, U5.13
/RED3: P2.38, U1.19
/RED4: P2.40, U1.18
/RED5: P2.15, U1.17
/RED6: P2.16, U1.16
/RED7: P2.18, U1.15
/RST: P2.13, U1.10
/SCK: P2.23, U1.37, U5.12
/SHDN: D3.2, JP2.2
/SS1: R2.2, U1.38, U5.2
/TGR_L1: SW8.1, U5.8
/TGR_R1: SW9.1, U5.28
/USB_D+: JP3.2, P1.3, P2.42
/USB_D-: JP3.1, P1.2, P2.41
/USB_ID: P1.4, P2.43
/VSYNC: P2.3, U1.11
/WiFi_D+: JP3.4, U4.3
/WiFi_D-: JP3.3, U4.2
/WiFi_EN: Q4.1, R23.1, U5.3
GND: AE1.2, BT1.2, C1.1, C2.2, C3.2, C5.2, C8.1, C9.2, C10.2, C11.2, C12.1, C13.1, C16.2, C18.1, C19.1, C20.2, C21.1, C22.1, C23.1, C24.2, C25.1, C26.2, P1.5, P1.6, P2.6, P2.9, P2.25, P2.30, P2.34, P2.39, Q1.2, Q2.1, Q3.3, R1.2, R2.1, R8.2, R10.1, R11.1, R16.2, R20.1, R21.1, R27.2, SW1.2, SW2.2, SW3.2, SW4.2, SW5.2, SW6.2, SW6#2.2, SW7.2, SW7#2.2, SW8.2, SW9.2, SW10.2, SW11.2, SW12.2, SW13.2, U1.6, U1.20, U1.32, U1.43, U1.48, U1.49, U1.50, U2.8, U2.9, U3.7, U4.4, U4.5, U5.10, U5.15, U5.16, U5.17, U6.2, U7.2
unnamed: AE1.1, C19.2, L1.2
unnamed: C2.1, C4.2, R9.1, R10.2
unnamed: C4.1, R12.2
unnamed: C6.1, U3.3
unnamed: C6.2, R12.1
unnamed: C7.1, U3.4
unnamed: C7.2, R11.2
unnamed: C8.2, Q4.3, U4.1
unnamed: C12.2, FB1.2, SP1.1
unnamed: C13.2, FB2.2, SP1.2
unnamed: C14.1, C15.2, Q2.4, Q2.7, Q2.8, R18.1
unnamed: C17.2, Q2.2, R19.2
unnamed: C18.2, L1.1, U4.6
unnamed: C26.1, JP1.1, U7.5
unnamed: D1.1, R1.1
unnamed: D2.1, D5.2, R13.1
unnamed: D2.2, D4.1, D5.1, D6.2, U2.4
unnamed: D3.1, Q3.2, R19.1, R22.1
unnamed: D4.2, D6.1, R14.1
unnamed: FB1.1, U3.8
unnamed: FB2.1, U3.5
unnamed: L2.1, U2.1
unnamed: Q1.1, R7.1, R8.1
unnamed: Q1.3, R3.1, R4.1, R5.1, R6.1
unnamed: R13.2, U2.2
unnamed: R14.2, U2.3
unnamed: R16.1, U2.5
unnamed: R20.2, U5.11
unnamed: R24.2, R27.1, U6.1
SW: C14.2, D3.3, R17.1, SW1.3
VAMP: C10.1, C11.1, JP1.2, R15.2, U3.6
VBAT: BT1.1, C9.1, C15.1, C21.2, L2.2, Q2.3, R17.2, R18.2, R24.1, U2.6
VBUS: C17.1, C22.2, C23.2, D1.2, P2.2, P2.4, Q2.5, Q2.6, Q4.2, R22.2, R23.2
VUSB: C3.1, C5.1, C20.1, C24.1, P1.1, U2.7

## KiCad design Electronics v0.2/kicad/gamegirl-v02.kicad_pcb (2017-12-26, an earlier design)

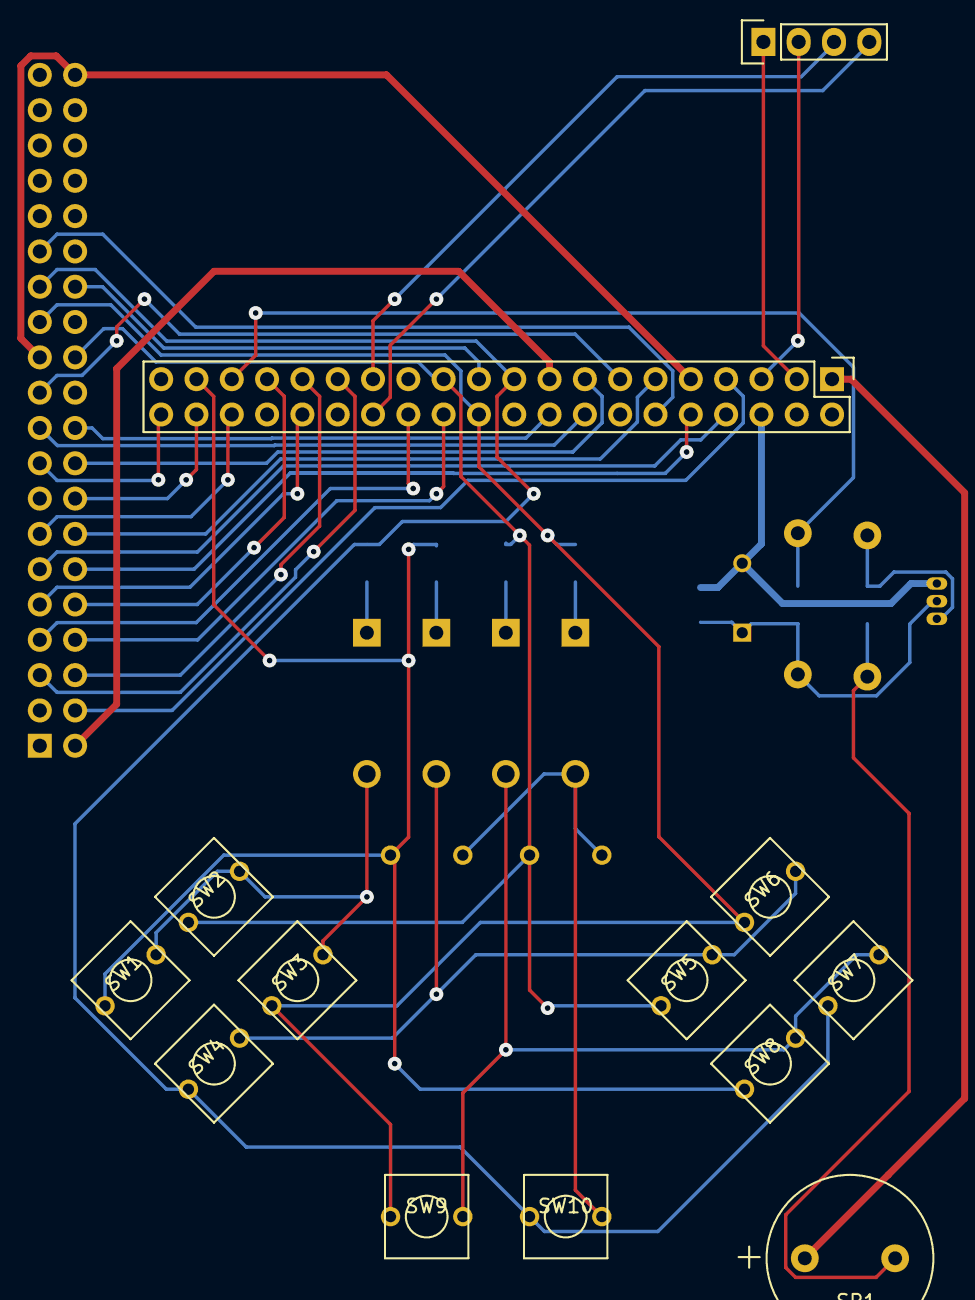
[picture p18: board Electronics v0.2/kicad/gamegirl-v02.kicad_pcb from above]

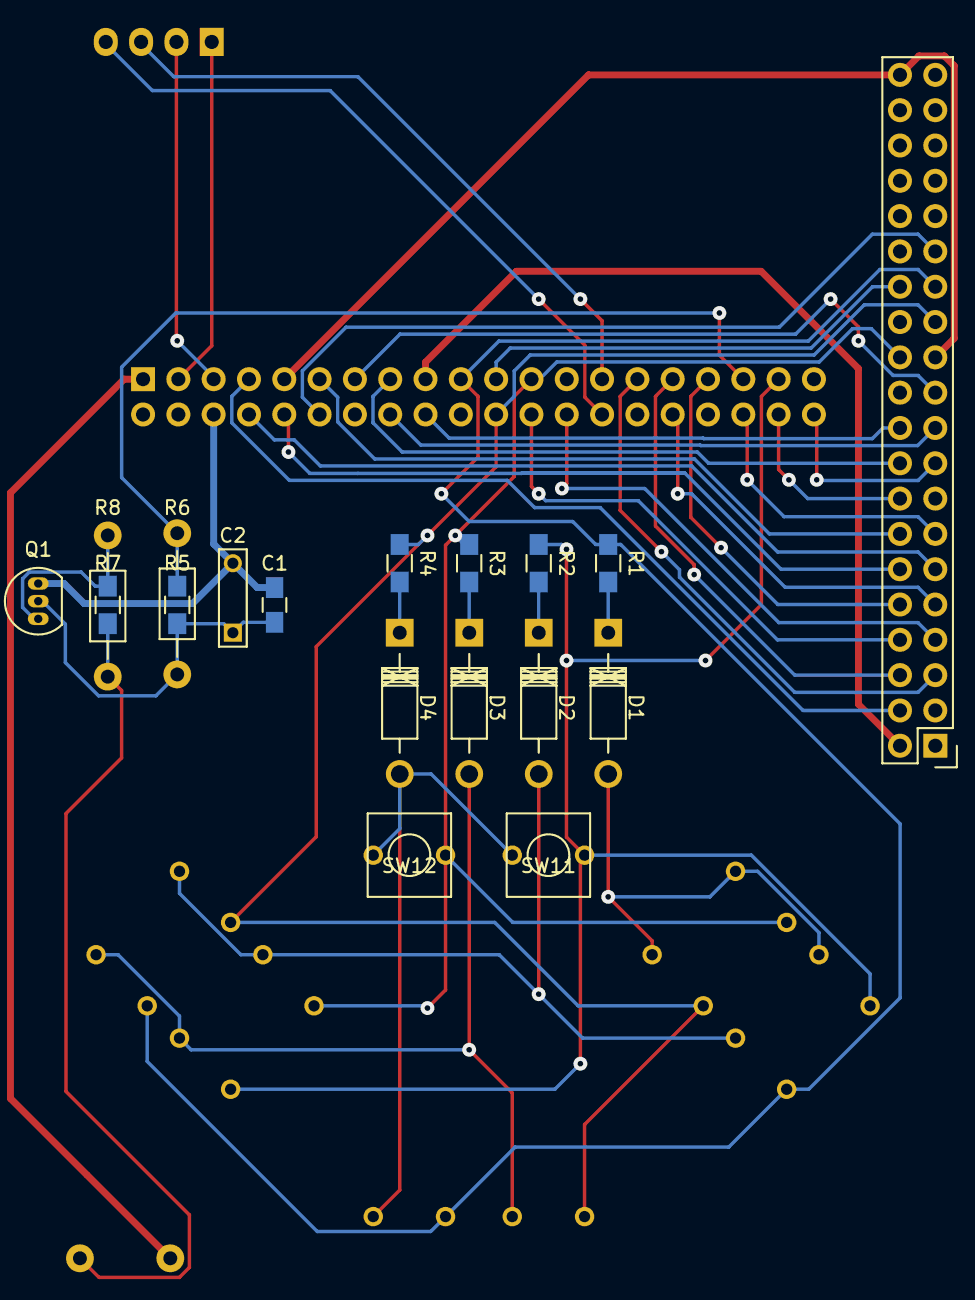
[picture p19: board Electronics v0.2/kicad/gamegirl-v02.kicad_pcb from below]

Board: 2 copper layers, 31 parts (18 on the bottom side), 42 nets.

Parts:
C1: 100nF; C_0805_HandSoldering
C2: 100nF; C_Rect_L7_W2_P5
D1, D2, D3, D4: D; Diode_DO-41_SOD81_Horizontal_RM10
P1, P3: CONN_02X20; Pin_Header_Straight_2x20
P2: CONN_01X04; Pin_Header_Straight_1x04
Q1: Q_NMOS_DGS; TO-92_Inline_Narrow_Oval
R1, R2, R3, R4: 1k; R_0805_HandSoldering
R5: 680; R_0805_HandSoldering
R6: 680; Resistor_Horizontal_RM10mm
R7: 0; R_0805_HandSoldering
R8: 0; Resistor_Horizontal_RM10mm
SP1: SPEAKER; Buzzer_12x6.5RM6.5
SW1, SW2, SW3, SW4, SW5, SW6, SW7, SW8, SW9, SW10, SW11, SW12: SW_PUSH; SW_PUSH_8x8_DIP

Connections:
+3V3: P1.2, P3.1, P3.17, SP1.1
/5V: P3.2, P3.4
//RESET_NC: P1.21, P3.13
/AUDIO: P3.35, R5.2, R6.2
/BL: P1.29, P3.12
/BLU3: P1.4, P3.7
/BLU4: P1.5, P3.29
/BLU5: P1.6, P3.31
/BLU6: P1.7, P3.26
/BLU7: P1.8, P3.24
/BTN1: P1.27, P3.19, R1.2, SW4.1, SW7.1, SW10.1
/BTN2: P3.37, R2.2, SW1.1, SW8.1, SW11.1
/BTN3: P1.24, P3.23, R3.2, SW2.1, SW5.1, SW12.1
/BTN4: P1.25, P3.22, R4.2, SW3.1, SW6.1, SW9.1
/CLOCK: P2.3, P3.27
/DB6: P1.9, P3.32
/DB7: P1.10, P3.33
/DB8: P1.11, P3.8
/DB9: P1.12, P3.10
/DB10: P1.13, P3.36
/DB11: P1.14, P3.11
/DB13: P1.16, P3.38
/DB14: P1.17, P3.40
/DB15: P1.18, P3.15
/DB16: P1.19, P3.16
/DB17: P1.20, P3.18
/DEN: P2.4, P3.28
/GPIO2: P2.1, P3.3
/GPIO3: P2.2, P3.5
/GPIO9: P1.28, P3.21
GND: C1.2, C2.2, P1.1, P1.23, P1.40, P3.6, P3.9, P3.14, P3.20, P3.25, P3.30, P3.34, P3.39, Q1.3
unnamed: C1.1, C2.1, Q1.2, R5.1, R6.1
unnamed: D1.1, R1.1
unnamed: D1.2, SW1.2, SW2.2, SW3.2
unnamed: D2.1, R2.1
unnamed: D2.2, SW4.2, SW5.2, SW6.2
unnamed: D3.1, R3.1
unnamed: D3.2, SW7.2, SW8.2, SW9.2
unnamed: D4.1, R4.1
unnamed: D4.2, SW10.2, SW11.2, SW12.2
unnamed: Q1.1, R7.2, R8.1
unnamed: R7.1, R8.2, SP1.2

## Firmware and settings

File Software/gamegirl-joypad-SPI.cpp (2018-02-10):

#include <stdio.h>
#include <stdlib.h>
#include <string.h>
#include <unistd.h>
#include <fcntl.h>
#include <errno.h>
#include <linux/input.h>
#include <linux/uinput.h>
#include <wiringPi.h>
#include <iostream>
#include <mcp23s17.h>
#include <time.h>

//Delay 2 seconds
Sleep(2);

#define die(str, args...) do { \
    perror(str); \
    exit(EXIT_FAILURE); \
  } while(0)

#define BASE    100 // offset for GPIO expander numbering

using namespace std;

//int _SHDN = 25; // GPIO25 - Power switch
int _mcp_cs = 18; // GPIO18 - MCP23S17 SPI Chip Select
int _lcd_cs = 26; // GPIO26 - LCD SPI Chip Select

/* MCP23S17 PINOUT   Pin 1(GPB0) start at GPIO 100 GPB0 = 100 | GPA0 = 108
 *   LBO | 1 (100) - GPB0     GPA7 - (115) 28 |  R1
 *   SS1 | 2 (101) - GPB1     GPA6 - (114) 27 |  Select
 *  WiFi | 3 (102) - GPB2     GPA5 - (113) 26 |  Start
 *  Left | 4 (103) - GPB3     GPA4 - (112) 25 |  Y (West)
 *    Up | 5 (104) - GPB4     GPA3 - (111) 24 |  X (North)
 * Right | 6 (105) - GPB5     GPA2 - (110) 23 |  A (East)
 *  Down | 7 (106) - GPB6     GPA1 - (109) 22 |  B (South)
 *    L1 | 8 (107) - GPB7     GPA0 - (108) 21 |  AMP 
 *   3V3 | 9       - VDD      INTA -       20 |  NC
 *   GND | 10      - VSS      INTB -       19 |  NC
 *   GND | 11      - CS        RST -       18 |  3V3
 *   SCK | 12      - SCK        A2 -       17 |  GND
 *  MOSI | 13      - SI         A1 -       16 |  GND
 *  MISO | 14      - SO         A0 -       15 |  GND    
 */

int btn_left = 103;
int btn_up = 104;
int btn_right = 105;
int btn_down = 106;
int btn_l1 = 107;
int btn_b = 109;
int btn_a = 110;
int btn_x = 111;
int btn_y = 112;
int btn_start = 113;
int btn_selec = 114;
int btn_r1 = 115;

int _LBO = 100; //Critical Low Battery alert, set as input pulled high
int _SS1 = 101; //SPI Chip Select pin for LCD, pull high
int _WiFi_EN = 102; //Pull high to enable
int _AMP_EN = 108; //Pull high to enable
bool WiFi_status = 1; //Sets to on by default
bool AMP_status = 1; //Sets to on by default

void set_key_bit(int fd, int button) {
  if (ioctl(fd, UI_SET_KEYBIT, button) < 0) {
    die("error: ioctl");
  }
}

void set_button_event(int fd, int button, int value) {
  struct input_event ev;
  ev.type = EV_KEY;
  ev.code = button;
  ev.value = value;
  if (write(fd, &ev, sizeof(struct input_event)) < 0) {
    die("error: write");
  }
}

int main() {
  unsigned i;

  // Initialize GPIO
  wiringPiSetupGpio();
    
  // Initialize MCP23S17
  pinMode(_lcd_cs, OUTPUT);
  pinMode(_mcp_cs, OUTPUT);
  digitalWrite(_lcd_cs, HIGH);
  digitalWrite(_mcp_cs, LOW);
  mcp23s17Setup(BASE, 1, 0) ;
  
  //Set button input pins on MCP23S17 to INPUT with PullUps enabled
  for (i = 2 ; i < 7 ; ++i){ //102 - 107
    pinMode(BASE+i, INPUT);
    pullUpDnControl(BASE+i,PUD_UP);
  }
  for (i = 9 ; i < 15 ; ++i){ //109-115
    pinMode(BASE+i, INPUT);
    pullUpDnControl(BASE+i,PUD_UP);
  }

  //Power switch setup
  pinMode(_SHDN, INPUT);
  pullUpDnControl(_SHDN,PUD_UP);
  
  //Sets Chip Select pin of LCD high disabling the SPI connection
  //pinMode(_SS1,OUTPUT);
  //pullUpDnControl(_SS1,PUD_UP);

  //Enables WiFi by default
  pinMode(_WiFi_EN,OUTPUT);
  digitalWrite(_WiFi_EN,1);//Enables power to WiFi module
  system("connmanctl enable wifi");//Enables WiFi connections
    
  //Sets up Audio, already on by default
  pinMode(_AMP_EN,OUTPUT);
  digitalWrite(_AMP_EN,1);
  
  // Initialise udev
  struct uinput_user_dev uidev;
  struct input_event ev;

  int fd = open("/dev/uinput", O_WRONLY | O_NONBLOCK);
  if (fd < 0)
    die("error: open");

  if (ioctl(fd, UI_SET_EVBIT, EV_KEY) < 0)
    die("error: ioctl");
  if (ioctl(fd, UI_SET_EVBIT, EV_REL) < 0)
    die("error: ioctl");
  if (ioctl(fd, UI_SET_EVBIT, EV_SYN) < 0)
    die("error: ioctl");

  set_key_bit(fd, BTN_DPAD_UP);
  set_key_bit(fd, BTN_DPAD_DOWN);
  set_key_bit(fd, BTN_DPAD_LEFT);
  set_key_bit(fd, BTN_DPAD_RIGHT);
  set_key_bit(fd, BTN_NORTH);
  set_key_bit(fd, BTN_SOUTH);
  set_key_bit(fd, BTN_WEST);
  set_key_bit(fd, BTN_EAST);
  set_key_bit(fd, BTN_START);
  set_key_bit(fd, BTN_SELECT);
  set_key_bit(fd, BTN_TL);
  set_key_bit(fd, BTN_TR);

  ioctl(fd, UI_SET_EVBIT, EV_ABS);
  ioctl(fd, UI_SET_ABSBIT, ABS_X);
  ioctl(fd, UI_SET_ABSBIT, ABS_Y);
  uidev.absmin[ABS_X] = 0;
  uidev.absmax[ABS_X] = 4;
  uidev.absmin[ABS_Y] = 0;
  uidev.absmax[ABS_Y] = 4;

  memset(&uidev, 0, sizeof(uidev));
  snprintf(uidev.name, UINPUT_MAX_NAME_SIZE, "Gamegirl Controller");
  uidev.id.bustype = BUS_USB;
  uidev.id.vendor  = 1;
  uidev.id.product = 1;
  uidev.id.version = 1;

  if (write(fd, &uidev, sizeof(uidev)) < 0)
    die("error: write");

  if (ioctl(fd, UI_DEV_CREATE) < 0)
    die("error: ioctl");

  int up_button, up_button_old         = 1;
  int down_button, down_button_old     = 1;
  int left_button, left_button_old     = 1;
  int right_button, right_button_old   = 1;
  int x_button, x_button_old           = 1;
  int b_button, b_button_old           = 1;
  int y_button, y_button_old           = 1;
  int a_button, a_button_old           = 1;
  int start_button, start_button_old   = 1;
  int selec_button, selec_button_old   = 1;
  int l1_button, l1_button_old         = 1;
  int r1_button, r1_button_old         = 1;
  int powerswitch                      = 1;
  int LBO                              = 1;
  int toggle_timeout                   = 0; //Toggle timeout for toggling WiFi or Amp
  int shdn_delay                       = 0; //Delay (debounce) for shutdown switch
  int LBO_delay                        = 0; //Delay  for LBO

  while (1) {
    // Read GPIO
    up_button_old     = up_button;
    down_button_old   = down_button;
    left_button_old   = left_button;
    right_button_old  = right_button;
    x_button_old      = x_button;
    b_button_old      = b_button;
    y_button_old      = y_button;
    a_button_old      = a_button;
    start_button_old  = start_button;
    selec_button_old  = selec_button;
    l1_button_old     = l1_button;
    r1_button_old     = r1_button;

    up_button    = digitalRead(btn_up); // 
    down_button  = digitalRead(btn_down); // 
    left_button  = digitalRead(btn_left); // 
    right_button = digitalRead(btn_right); // 
    x_button     = digitalRead(btn_x); //
    b_button     = digitalRead(btn_b); // 
    y_button     = digitalRead(btn_y); // 
    a_button     = digitalRead(btn_a); //
    start_button = digitalRead(btn_start); //
    selec_button = digitalRead(btn_selec); // 
    l1_button    = digitalRead(btn_l1); // 
    r1_button    = digitalRead(btn_r1); // 
    powerswitch  = digitalRead(_SHDN); //
    LBO          = digitalRead(_LBO); //

    // Write to udev
    if (up_button != up_button_old) {
      set_button_event(fd, BTN_DPAD_UP, up_button != 0);
    }

    if (down_button != down_button_old) {
      set_button_event(fd, BTN_DPAD_DOWN, down_button != 0);
    }

    if (left_button != left_button_old) {
      set_button_event(fd, BTN_DPAD_LEFT, left_button != 0);
    }

    if (right_button != right_button_old) {
      set_button_event(fd, BTN_DPAD_RIGHT, right_button != 0);
    }

    if (x_button != x_button_old) {
      set_button_event(fd, BTN_NORTH, x_button != 0);
    }

    if (b_button != b_button_old) {
      set_button_event(fd, BTN_SOUTH, b_button != 0);
    }

    if (y_button != y_button_old) {
      set_button_event(fd, BTN_WEST, y_button != 0);
    }

    if (a_button != a_button_old) {
      set_button_event(fd, BTN_EAST, a_button != 0);
    }

    if (start_button != start_button_old) {
      set_button_event(fd, BTN_START, start_button != 0);
    }

    if (selec_button == 0 && toggle_timeout > 119){ //mode button | Sel+L1 WiFi toggle | Sel+R1 = Amp toggle | 
      if (l1_button == 0 ){
        WiFi_status = !WiFi_status;
        digitalWrite(_WiFi_EN, WiFi_status); //For Zero v1.3 using WiFi Module
        if(WiFi_status == 1)//For Zero W WiFi control
            system("connmanctl enable wifi");
        else
            system("connmanctl disable wifi");
        toggle_timeout = 0;
      }
      else if(r1_button == 0){
        AMP_status = !AMP_status;
        digitalWrite(_AMP_EN,AMP_status);
        toggle_timeout = 0;
      }
    }
    else if(selec_button != selec_button_old)
        set_button_event(fd, BTN_SELECT, selec_button != 0);
    }

    if (l1_button != l1_button_old) {
      set_button_event(fd, BTN_TL, l1_button != 0);
    }

    if (r1_button != r1_button_old) {
      set_button_event(fd, BTN_TR, r1_button != 0);
    }

    if (LBO == 0) {
      LBO_delay++;
      if(LBO_delay > 59) {
        system("echo Critically low battery shutting down now!\n");
        system("echo -n \"SHUTDOWN\" | nc -u -w1 127.0.0.1 55355");
    }
    else
      LBO_delay = 0;

    if (powerswitch == 0) {
      shdn_delay++;
      if(shdn_delay > 59) {
        system("echo Power button toggled, shutting down now!\n");
        system("echo -n \"SHUTDOWN\" | nc -u -w1 127.0.0.1 55355");
      }
    }
    else
        shdn_delay = 0;

    memset(&ev, 0, sizeof(struct input_event));
    ev.type = EV_SYN;
    ev.code = SYN_REPORT;
    ev.value = 0;
    if (write(fd, &ev, sizeof(struct input_event)) < 0)
      die("error: write");

    delay(1000/120);
    
    if(toggle_timeout < 119)
      toggle_timeout++;
  }

  // Destroy udev
  if (ioctl(fd, UI_DEV_DESTROY) < 0)
    die("error: ioctl");

  close(fd);
  
  return 0;
}

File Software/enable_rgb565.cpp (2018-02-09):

#include <wiringPi.h>
#include <wiringPiSPI.h>

using namespace std;

#define ILI9340_SWRESET 0x01
#define ILI9340_SLPOUT  0x11
#define ILI9340_GAMMASET 0x26
#define ILI9340_DISPOFF 0x28
#define ILI9340_DISPON  0x29
#define ILI9340_MADCTL  0x36
#define ILI9340_PIXFMT  0x3A

#define ILI9340_PWCTR1  0xC0
#define ILI9340_PWCTR2  0xC1
#define ILI9340_VMCTR1  0xC5
#define ILI9340_VMCTR2  0xC7

#define ILI9340_GMCTRP1 0xE0
#define ILI9340_GMCTRN1 0xE1

#define ILI9340_CASET   0x2A
#define ILI9340_PASET   0x2B
#define ILI9340_RAMWR   0x2C

int _clock = 0; // GPIO 0
int _den = 1; // GPIO 1
int _vsync = 2; // GPIO 2
int _hsync = 3; // GPIO 3
int _blu3 = 4; // GPIO 4
int _blu4 = 5; // GPIO 5
int _blu5 = 6; // GPIO 6
int _blu6 = 25; // GPIO 7
int _blu7 = 26; // GPIO 8
int _gre2 = 12; // GPIO 12
int _gre3 = 13; // GPIO 13
int _gre4 = 14; // GPIO 14
int _gre5 = 15; // GPIO 15
int _gre6 = 16; // GPIO 16
int _gre7 = 17; // GPIO 17
int _red3 = 20; // GPIO 20
int _red4 = 21; // GPIO 21
int _red5 = 22; // GPIO 22
int _red6 = 23; // GPIO 23
int _red7 = 24; // GPIO 24

int _dc = 25; // GPIO 25    | LCD DC
int _rst = 27; // GPIO 27   | LCD Reset
int _mosi = 10; // GPIO 10  | SPI MOSI
int _miso = 9; // GPIO 9    | SPI MISO
int _sclk = 11; // GPIO 11  | SPI Clock
int _lcd_cs = 26; //GPIO26  | LCD SPI Chip Select
int _mcp_cs = 18; // GPIO 18| MCP23S17 Chip Select
int _audio = 19; //         | RPi PWM Audio

int _channel = 1;
int _speed = 80000000;//80000000;//500000;//80000000;

void spiwritearray(unsigned char c[], int length) {
	wiringPiSPIDataRW(_channel, c, length);
}

void spiwrite(unsigned char c) {
	wiringPiSPIDataRW(_channel, &c, 1);
}

void writecommand(int c) {
  digitalWrite(_dc, LOW);
//  digitalWrite(_sclk, LOW);
  
  spiwrite(c);
}

void writedata(int c) {
  digitalWrite(_dc, HIGH);
//  digitalWrite(_sclk, LOW);
  
  spiwrite(c);
}

void begin() {
  pinMode(_rst, OUTPUT);
  digitalWrite(_rst, LOW);
  
  pinMode(_dc, OUTPUT);

  // Initialise SPI
  pinMode(_lcd_cs, OUTPUT);
  pinMode(_mcp_cs, OUTPUT);
  digitalWrite(_lcd_cs, LOW);
  digitalWrite(_mcp_cs, HIGH);
  wiringPiSPISetup(_channel, _speed);
  
  // Initialise DPI pins
  const int ALT2 = 0b110;
  pinModeAlt(_clock, ALT2);
  pinModeAlt(_den, ALT2);
  pinModeAlt(_vsync, ALT2);
  pinModeAlt(_hsync, ALT2);
  pinModeAlt(_blu3, ALT2);
  pinModeAlt(_blu4, ALT2);
  pinModeAlt(_blu5, ALT2);
  pinModeAlt(_blu6, ALT2);
  pinModeAlt(_blu7, ALT2);
  pinModeAlt(_gre2, ALT2);
  pinModeAlt(_gre3, ALT2);
  pinModeAlt(_gre4, ALT2);
  pinModeAlt(_gre5, ALT2);
  pinModeAlt(_gre6, ALT2);
  pinModeAlt(_gre7, ALT2);
  pinModeAlt(_red3, ALT2);
  pinModeAlt(_red4, ALT2);
  pinModeAlt(_red5, ALT2);
  pinModeAlt(_red6, ALT2);
  pinModeAlt(_red7, ALT2);
  
  // toggle RST low to reset
  if (_rst > 0) {
    digitalWrite(_rst, HIGH);
    delay(5);
    digitalWrite(_rst, LOW);
    delay(20);
    digitalWrite(_rst, HIGH);
    delay(150);
  }
  
  writecommand(ILI9340_SWRESET);
  delay(1);
  
  writecommand(ILI9340_DISPOFF);
  
  /*
  writecommand(0xCA);
  writedata(0xC3);
  writedata(0x08);
  writedata(0x50);
  */
  
  writecommand(0xEF);
  writedata(0x03);
  writedata(0x80);
  writedata(0x02);
  
  writecommand(0xCF); // LCD_POWERB
  writedata(0x00);
  writedata(0XC1);
  writedata(0X30);
  
  writecommand(0xED); // LCD_POWER_SEQ
  writedata(0x64);
  writedata(0x03);
  writedata(0X12);
  writedata(0X81);
  
  writecommand(0xE8); // LCD_DTCA
  writedata(0x85);
  writedata(0x00);
  writedata(0x78);
  
  writecommand(0xCB); // LCD_POWERA
  writedata(0x39);
  writedata(0x2C);
  writedata(0x00);
  writedata(0x34);
  writedata(0x02);
  
  writecommand(0xF7); // LCD_PRC
  writedata(0x20);
  
  writecommand(0xEA); // LCD_DTCB
  writedata(0x00);
  writedata(0x00);
  
  /*
  writecommand(0xB1); // LCD_FRC // Frame Rate Control
  writedata(0x00);
  writedata(0b00010000); // 0x1B=70 FPS
  */
  // LCD_DFC
  
  writecommand(ILI9340_PWCTR1);    //Power control // 0xC0
  writedata(0x23);
  
  writecommand(ILI9340_PWCTR2);    //Power control // 0xC1
  writedata(0x10);
  
  writecommand(ILI9340_VMCTR1);    //VCM control // 0xC5
  writedata(0x3e); // 0x31?
  writedata(0x28); // 0x3C?
  
  writecommand(ILI9340_VMCTR2);    //VCM control2 // 0xC7
  writedata(0x86); // 0xC0? 0x86?
  
  writecommand(ILI9340_MADCTL);    // Memory Access Control  // 0x36
  writedata(0b01001000); // MY=1, MX=0, MV=1 (0b01000000), BGR=1 (0b01001000)
  
  writecommand(ILI9340_PIXFMT); // 0x3A
  writedata(0x55); // 16-bit: DPI=101 // 18-bit=0x66
  
  writecommand(0xF2); // 3Gamma Function Disable
  writedata(0x02);
  
  writecommand(0xB0); // RGB Interface Signal Control
  writedata(0b11000011); // memory=1 RCM=10, 0, VSPL=0 (low level sync clock), HSPL=0, DPL=1 (dotclock fetched at rising time), EPL=0 (high enable)
  // 0xC2? DEFAULT: 0x40, 0b01000000
  
  writecommand(0xB6); // LCD_DFC // Display Function Control
  writedata(0x0A);
  writedata(0b10000010); // =0x82
  writedata(0x27);
  writedata(0x08); // PCDIV = 4
  
  writecommand(0x2A); // column set
  writedata(0x00);
  writedata(0x00);
  writedata(0x00);
  writedata(0xEF);
  
  writecommand(0x2B); // Page set
  writedata(0x00);
  writedata(0x00);
  writedata(0x01);
  writedata(0x3F);
  
  writecommand(0xF6); // Interface Control
  writedata(0x01);
  writedata(0b00000000); // EPF=11
  writedata(0b00001010); // 16-bit RGB=0b00000110, DM=01, RM=1, RIM=0
  
  writecommand(0x2C); // GRAM register
  delay(1);
  
  writecommand(ILI9340_GAMMASET);    //Gamma curve selected // 0x26
  writedata(0x01);
  
  writecommand(ILI9340_GMCTRP1);    //Set Gamma // 0xE0
  writedata(0x0F);
  writedata(0x31);
  writedata(0x2B);
  writedata(0x0C);
  writedata(0x0E);
  writedata(0x08);
  writedata(0x4E);
  writedata(0xF1);
  writedata(0x37);
  writedata(0x07);
  writedata(0x10);
  writedata(0x03);
  writedata(0x0E);
  writedata(0x09);
  writedata(0x00);
  
  writecommand(ILI9340_GMCTRN1);    //Set Gamma // 0xE1
  writedata(0x00);
  writedata(0x0E);
  writedata(0x14);
  writedata(0x03);
  writedata(0x11);
  writedata(0x07);
  writedata(0x31);
  writedata(0xC1);
  writedata(0x48);
  writedata(0x08);
  writedata(0x0F);
  writedata(0x0C);
  writedata(0x31);
  writedata(0x36);
  writedata(0x0F);
  
  writecommand(0xB5); // Blanking Porch Control
  writedata(0x04); // VFP
  writedata(0x02); // VBP
  writedata(0x0A); // HFP
  writedata(0x14); // 0x14? 0x16? HBP
  
  writecommand(0x2D); // Color Set LUT
  for (unsigned char i = 0; i < 32; i++) {
    writedata(63*i/31);
  }
  for (unsigned char i = 0; i < 64; i++) {
    writedata(i);
  }
  for (unsigned char i = 0; i < 32; i++) {
    writedata(63*i/31);
  }
  
  writecommand(ILI9340_SLPOUT);    //Exit Sleep
  delay(120);
  writecommand(ILI9340_DISPON);    //Display on
  delay(120);
  writecommand(0x2C); // memory write
  
  // Initialise backlight
//  pinMode(_backlight, PWM_OUTPUT);
//  pwmWrite(_backlight, 1023);
  //pinMode(_backlight, OUTPUT);
  //digitalWrite(_backlight, HIGH);
  
  /*
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

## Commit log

2016-12-19 Adding prototype v0.2 schematic
    v0.2 schematic
    Gamegirl_Controller.cfg for v0.2
    [Gamegirl_Controller.cfg]
2017-01-01 Create Software directory
    [Gamegirl_Controller.cfg]
2017-01-01 Add v0.1 schematic
2017-01-01 Create Mechanical directory
    [Gamegirl-2016-07-11.STEP]
2017-01-02 Final v0.2 schematic
2017-01-14 Added different prototype versions
    * v0.2, v0.2.1, v0.3 descriptions added
    * Complete readme revisioned
2017-01-18 Added BOM, updated README
2017-01-24 Octopart BOM; fixed PDF links
2017-02-17 Updated V0.2.1 prototype image
2017-03-20 v0.2.1 BOM
    [Gamegirl_v0.2.1_BOM.csv]
2017-03-20 Added v0.2.1 BOM link
2017-04-04 gamegirl v0.2.1 schematic
2017-06-01 Screen initialization of ili9341
    Initializes ili9341 LCD's into DPI mode over SPI and sets Raspberry Pi into DPI 16-bit (RGB565) mode.
2017-06-23 Changed SPI channel, added PWR switch delay
    Changed SPI channel to match the one used in "enable_rgb565.cpp"
    Updated toggling of WiFi and AMP for more reliablility
    Added a 0.5s delay on Power switch and low battery input for debouncing and reduce unintended shutdown.
2017-12-26 Add Kicad files
    [Gamegirl_v0.2.1_BOM.csv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]
2018-02-09 Added use of SPI chip select pins
    Add GPIO26 to be LCD chip select pin
    Changed GPIO18 to be MCP23S17 chip select pin
    Ensured the MCP is not listening and talking on the SPI bus while the LCD is initializing
2018-02-10 Added use of SPI chip select pins
